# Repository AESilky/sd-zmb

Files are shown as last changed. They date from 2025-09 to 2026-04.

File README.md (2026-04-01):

# Silky Design & CMOS1 - Z80 Retro Motherboard

This is a Z80-based 'retro-style' Single Board Computer (motherboard).

The motherboard includes enough to run stand-alone.
That includes:

1. Z80 CPU
2. Selectable CPU clock frequencies
3. Reset circuit, divided into a POR board/system reset and a Z80/CPU only reset
4. Memory Management Unit (MMU) that provides bank selecting 8 of 64 8K banks (2M physical address)
5. 512K bytes RAM and 512K bytes Flash ROM
6. 2 Serial ports. One with USB 'device' interface, one with USB host interface (KBD)
7. RP2040 module to provide USB Host (for a keyboard) and an SD Card interface. The SD Card can be used for:
   a. EEPROM (like) configuration storage
   b. Virtual IDE drive(s)
   c. Raw SD Card access
   d. Multicolor LED indicator (via the onboard NeoPixel)
8. Programmable BAUD rate generator
9. Periodic interrupt generated by 3rd CTC channel
10. OLED or TFT graphics display (can be used for graphics or multi-line text)
11. RC2014-80 Extended/Enhanced Bus

The design started with much more on the board, but has been paired down to make the size and complexity of the board more reasonable. The 'features' that have been removed have been moved into projects of their own to be built-out as expansion boards.

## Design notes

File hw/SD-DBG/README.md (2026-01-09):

# ZMB Debug Board

The ZMB Debug Board is intended to provide debugging functionality to accompany the Mini-ZED Monitor firmware.

## Features

The board plugs into the RC80 bus and provides:

1. Jumper selectable memory wait-state generation, 0 to 8 wait states on memory operations.
2. Jumper selectable I/O wait-state generation, 0 to 8 wait states on I/O operations.
3. Reset push-button switch for Board/System reset. Holds the board/system in reset as long as the switch is pressed.
4. Reset push-button switch for CPU only reset. Holds the CPU in reset as long as the switch is pressed.
5. Breakpoint push-button switch. Generates the Z80 'special' reset signal when pressed.
6. Breakpoint hardware. Generates the Z80 'special' reset when selected conditions are met (see below for details)
7. LED indicators for the Z80 control signals (WAIT, HALT, RFSH, M1, MREQ, IORQ, RD, WR)
8. Optional Der Blinkenlights for A0-23 and D0-7. These are powered by a USB-C (power only) connector.

## Breakpoint Conditions

The breakpoint logic allows selecting:

1. Instruction fetch from a specific address (24 or 16 bit address)
2. Instruction fetch from any address (used for single-step)
3. Memory read from a specific address (24 or 16 bit address)
4. Memory write to a specific address (24 or 16 bit address)
5. Any memory operation on a specific address (24 or 16 bit address)
6. I/O read from a specific address (16 or 8 bit address)
7. I/O write to a specific address (16 or 8 bit address)
8. Any I/O operation on a specific address (16 or 8 bit address)

When the condition is met the Z80 'special' reset is generated, then the PC address of the following (ignored) instruction fetch address is recorded. Along with the PC address, the breakpoint condition that was met is also recorded. The recorded address and breakpoint condition can be read using I/O operations.

## High-Level Debug Monitor Description

This section provides a very high-level description of the Debug Monitor functionality. For complete information, see the Mini-ZDB Manual.

The monitor uses the terminal input/output subsystem of the ZMB to communicate with the user. It works stand-alone and in conjunction with the ZMB Debug Board (ZDB) to:

1. Display the CPU registers
2. Set the value of CPU registers that will be used when code is run
3. Display the contents of memory (ZDB not required)
4. Modify the contents of RAM memory (ZDB not required)
5. Display data from an I/O port (ZDB not required)
6. Write data to an I/O port (ZDB not required)
7. Run code and break:
   1. at one of 10 'soft' breakpoints (break location in RAM, ZDB not required)
   2. at any single location (location in RAM or ROM, ZDB required)
   3. when a memory write occurs to a specific address (ZDB required)
   4. when a memory read occurs from a specific address (ZDB required)
   5. when an I/O write occurs to a specific port (8 or 16 bit address, ZDB required)
   6. when an I/O read occurs from a specific port (8 or 16 bit address, ZDB required)
8. Single-step code (in RAM or ROM, ZDB required)
9. Perform operations that can be helpful in troubleshooting/repairing hardware problems, including:
   1. repetitive write of a specific data byte to a memory location
   2. repetitive read from a memory location *
   3. repetitive write of a specific data byte to a port
   4. repetitive read from a port
   5. run a memory test using a number of different approaches (data patterns)
10. Write a data file (ROM image, or portion) to the Flash. The source of the image can be:
    1. A file on the SD Card
    2. Received from the host computer using the serial port
11. Save an image of the Flash (or portion of it), as a data file. The destination can be:
    1. A file on the SD Card
    2. Sent to the host computer using the serial port

## RC80 Bus Debug Board (ZDB) Key Operation Details

This section provides details of how the ZDB performs key operations.

### Wait-State Generation

The ZDB can introduce a selectable number of wait-states in memory and/or I/O operations. This can allow using expansion boards that are not capable of running at the speed of the ZMB, but weren't designed to request wait-states.

The circuit that generates the WAIT- signal is similar for both memory and I/O. Two identical circuits are used, one for memory and one for I/O.

1. MREQ-/IORQ- holds a shift register (of the applicable circuit) in reset while the signal isn't active, resulting in all 8 of the shift register outputs being low.
2. When the MREQ-/IORQ- signal becomes active, the shift register clocks a 1 in on each rising edge of the CPU clock.
3. As 1 is clocked in, it appears on the shift register outputs from 1-8.
4. A jumper is placed on 1 of 9 positions:
   1. GND, which never generates a WAIT- signal
   2. One of the 8 shift register outputs, which results in 1 wait state through 8 wait states being generated

### Z80 Special Reset Generation

The circuit to generate the Z80 special reset is from the Zilog patent, U.S. Patent 4,486,827. It is triggered by either the press of a push-button switch or the breakpoint condition met circuit.

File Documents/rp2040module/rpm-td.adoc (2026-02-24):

= RP2040-Module: Technical Design
include::../adoc/settings.adoc[]
:organization: SilkyDESIGN
// Multi-Part Book: [Quick Start][User Guide]
:doctype: book
:description: Technical design for the RP2040 Module.
:imagesdir: ./images

toc::[]

[introduction]
= Introduction
The RP2040 Module is used to provide an interface from an 8-bit CPU bus to multiple peripherals, 
such as a USB keyboard, SD-Card, RTC and other I2C devices. 

The module uses GPIO pins for the CPU bus
interface, with 8 data bits, a module select *ms-*(((ms-, module select))), read *rd-*, write *wr-*, 
and address (control/data) *addr*, inputs, and wait *wait-* and interrupt request *int-* outputs.

It uses the built-in USB port to interface to a keyboard, SPI (through GPIO pins) for an SD-Card, and I2C 
(through GPIO pins) for an RTC module (and possibly other devices).

[preface%nonfacing]
= Preface
Needed?

[%nonfacing]
== Address 0/1 - Control and Data (Registers)
The module uses two addresses in the main system. One for module control and the other for peripheral
control and data. Each address can be written and read. The specifics of what is written and read
depends on the address and the selected peripheral.

=== Addr LOW - Module Control (Register 0)
The *addr* pin LOW selects the *Module Control* register. The Module Control register contains the
following bits:

[cols="1,1,1,1,1,1,1,1,1"]
|===
|7|6|5|4|3|2|1|0|
| | | | | | | |*| Function Control/Data
| | | | |*|*|*| | Function Select
| | | |*| | | | | Interrupt Enable
| | | | | | | | |
| |*| | | | | | | Busy (read)
|*| | | | | | | | Interrupt Pending (read)
|*| | | | | | | | Interrupt Being Serviced/Clear
|===

=== Addr HIGH - Function Dependent (Register 1)
The *addr* pin HIGH selects register 1 which is used by the module functions. The meaning/use of
register 1 depends on which function is selected. It also depends on the state of bit-0 of the
control register. When the control register bit-0 is 0, register 1 is typically used for function
control. When the control register bit-0 is 1, register 1 is typically used for data.

The following sections describe Register 0 and the use of Register 1 for the main module control
functionality in more detail.

=== Register 0 Bit Usage
Register 0 is used to control the high-level functionality of the module as follows:

Bit 0       Controls whether Register 1 is function control (0) or function data (1)
Bits 1-3    Function select
    000     Module
    001     Keyboard
    010     RTC
    011     -TDB-
    100     SD Card (func 0 - IDE)
    101     SD Card (func 1 - FILES)
    110     SD Card (func 2 - RAW)
    111     SD Card (func 3 - NVRAM)
Bit 4       Interrupt Enable (write) / Enabled (read)
Bit 5       -TBD-
Bit 6       -TBD-
Bit 7       Interrupt Pending (read)
            Interrupt Being Serviced (write '1')
            Interrupt Clear (write '0')

==== Bit 7 - Interrupt Pending (read) / Servicing:Clear (write 1:0)
When reading register 0, bit 7 '1' indicates that an interrupt is pending. When an interrupt is
pending, writing bit 7 as '1' at the same time as selecting a function with bits 1-3 (along with bit 0)
pauses the currently selected function, stores it, and selects the indicated function. This allows
servicing an interrupt from a function that is different than the function currently in use. Each
time register 0 is written, but 7 should be written as 1 while interrupts are being serviced. Once
bit 7 has been written with '1', writing it with '0' resets the interrupt pending flag and will
allow the module to generate another interrupt if interrupts are enabled (bit 4 is 1). In addition to
resetting the interrupt pending, the write of '0' also restores the previously selected function as
the active function regardless of what is written to bits 0-3. This allows the continued processing
of the interrupted function without any additional changes to the module.

[%nonfacing]
== Bus Service
The module uses 8 GPIO pins for a bidirectional data bus, 4 GPIO for module select, write, read, and address
inputs, and 2 GPIO pins as wait request and interrupt request outputs. The GPIOs are monitored and
controlled by the RP2040 Programmable I/O (PIO).

=== PIO State Machine Use
Two state machines are used to wait for Module Select together with Read or Write. One State
Machine waits on an internal interrupt bit to be set, signalling that the data bus needs to be
read and the data transferred in.

One State Machine waits on Module Select (MS-). Once MS- is detected, RD- is checked along with MS-.
If both are detected together the WAIT- pin is activated and an interrupt is generated to the module CPU

A second State Machine waits on Module Select (MS-). Once MS- is detected, WR- is checked along with MS-.
If both are detected together the WAIT- pin is activated and an interrupt bit is set to trigger
another State Machine to read the bus.

A third State Machine waits on an interrupt bit to be set. Once the interrupt is set, allowing the
State Machine to continue, the 8 data pins are read and the data pushed to the ISR. The State
Machine then goes back to waiting on the interrupt bit.

A forth State Machine waits on data arriving in the OSR and when data is available it sets the
8 data pins to output, writes the byte, clears the WAIT- pin, and sets in interrupt bit.

[%nonfacing]
==== ((sec-level-4))
This is a 4th level section

ifeval::["{backend}" == "pdf"]
[index]
= Index
endif::[]

[colophon]
= Colophon
This is the design document for ((RP2040-Module)) ((Version 0.1.0))
Edit date: 1-17-2026

MIT License

Copyright (c) 2020-24 PyKOB - MorseKOB in Python

This document is authored using *asciidoc*, and the pdf version rendered through
*asciidoctor-pdf*, to create a manual that is more readable and more pleasing to the eye.

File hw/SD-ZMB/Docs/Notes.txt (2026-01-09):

We should replace the act244 with a 245 and add a 245 to the lower address bus, with that the full address bus is buffered as well as  ZMREQ. ZIORQ, RD and WR.  Add a 125 or 367 for the bus status read.  That allows us to move some if not most of the signals to the Z80 no buffer delays. We need to get MREQ out of the paging RAM, to give us more access time. Please add pull ups to ZMREQ, ZIORQ, ZRD and ZWR so they are a known state when tri-stated and not floating.

That is what I am thinking to minimize the delays between the Z80 and memory, plus the onboard devices (no we treat our board per as local friends). We still need to consider the expansion board area and instruction fetches maybe those off board accesses will require a wait state to be inserted. The Z80 is a very slow device in respect to the clock, including its needs for data setup. Only 2 clock times for all that work to be done. So the paging register is always in series, we must have it on the first available stable signal (addresses), and take advantage some of the control signals might be ok with the MREQ delayed by a ½ of a clock. All of this close timing is connected to M1 (instruction fetch). We do have M1 which is also based off the start of the 2 bit clock cycle, so we know it’s a read, nothing else. Don’t forget that with only 2 cycles to make all this happen. 

I am going with the assumption that we are targeting to run at 6 MHz or 12 MHz using a Z84C0006 or a Z84C0020. The SRAM and FLASH would have a 55ns access time.

Our first priority is to get the addresses stable and to the devices in the quickest way. Next is to keep the memory devices RD/WR controls fast. At 6MHz CLK to address is 90ns. CLK to MREQ is a 154ns. Including the required setup for data in is 333ns -30ns of setup, just say 300ns.

At 12MHz assuming a z80c0020, CLK to address is 57ns, and CLK to MREQ 87ns with a two cycle time of 167ns, minus the 12ns of setup time for the z80. I think that gives us 98ns off the address and only 80ns from MREQ not accounting for any additional delays in the logic.

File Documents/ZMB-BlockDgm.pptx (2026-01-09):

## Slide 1

ZMB Block Diagram (ES)

RESET
- Board (driven by):
  - Power-On
  - Push-BTN
  - Bus Signal
- Z80 (driven by):
  - Board-RST
  - Bus Signal

I/O
Decode

BRD-Ctrl WR

DATA

BRDRST

PgEN WR

D0

Z80RST

Paging
Enable

Z80RST
disables
paging

Pg Enable

MMU & Memory
(64KB Logical : 2MB Physical)

When Paging is disabled PA13-PA23 are 0 (ROM is selected)

COM1
(D,RTC,CTS)

COM2
(TX,RX)

BRD Status (via DCDA,CTSB)

Paging-Enabled, NMI-Enabled

Misc Ctrl (via HSHK)

SIO

A[0..1]

SIO-SEL

INT

DATA

Ext INT REQ (via DCDB)

CTC-SEL

A[0..1]

DATA

CTC

- CH1: BAUD1
- CH2: BAUD2
- CH3: Periodic INT

BAUD1

BAUD2

USB

INT

Z80RST

Page-Seg
Register

Page[PA:13-15]

Paging Ctrl

Flash
ROM
[00:0000-07:FFFF]
(512MB)

RAM
[08:0000-0F:FFFF]
(512MB)

Available
(to expansion boards)
[10:0000-1F:FFFF]
(1MB)

PS-Reg WR

ADDR:12-15

DATA

PS-Reg WR

Pg Enable

Physical Address
[00:0000-1F:FFFF]

PS-Reg RD

PgEn WR

BRD-Ctrl WR

DisplayPanel-SEL

CTC-SEL

SIO-SEL

SDMod-SEL

Board
Control

- NMI Enable
- LED[0..4]

LED[0..4]

NMI Enable

PS-Reg RD

DATA

PS-RD

Display Panel

DisplayPanel-SEL

A[0..1]

DATA

USB KBD
SD Card
(module)

SDMod-SEL

A[0..1]

DATA

COM2

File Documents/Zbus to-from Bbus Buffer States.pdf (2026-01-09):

In the following…
ZD: Z80 Data | ZA: Z80 Address | ZC: Z80 Control (MREQ, IORQ, WR, RD)
BD: Bus (expansion) Data | BA: Bus Address | BC: Bus Control
MB: Main Board Device
EB: Expansion Board Device (on the Bus)
Required: This must occur
Allowed: This can occur (it will not bother anything)
Prohibited: This is not allowed
Master | Operation | ZD<=>BD | ZA<=>BA | ZC<=>BC
| | Required | Allowed | Prohibited | Valid nS (long path) | Required | Allowed | Prohibited | Valid nS (long path) | Required | Allowed | Prohibited | Valid nS (long path)

Z80 Master
| MB Memory RD (IF, MR below 1M) | | ZD => BD | BD <= ZD | | | ZA0-12+MHA13-23=>BA | BA<=ZA | | | ZC=>BC | BC<=ZC
BUS Memory RD (IF, MR above 1M) | BD => ZD | MB device on ZD | 52 (BUSMEM-) | ZA0-12+MHA13-23=>BA | ZC=>BC
MB Memory WR (MW below 1M) | ZD => BD | BD => ZD | ZA0-12+MHA13-23=>BA | BA<=ZA | ZC=>BC | BC<=ZC
BUS Memory WR (MW above 1M) | ZD => BD | MB device on ZD | 52 (BUSMEM-) | ZA0-12+MHA13-23=>BA | ZC=>BC
MB Refresh | | | ZA=>BA | BA<=ZA | ZC=>BC | BC<=ZC
MB I/O RD | ZD => BD | BD <= ZD | ZA0-15=>BA | BA<=ZA | ZC=>BC | BC<=ZC
BUS I/O RD | BD => ZD | MB device on ZD | 52 (BUSIO-) | ZA0-15=>BA | ZC=>BC
MB I/O WR | ZD => BD | BD => ZD | ZA0-15=>BA | BA<=ZA | ZC=>BC | BC<=ZC
BUS i/O WR | ZD => BD | 52 (BUSIO-) | ZA0-15=>BA | ZC=>BC
MB INT-ACK | ZD => BD | | ZA0-15=>BA | BA<=ZA | ZC=>BC | BC<=ZC
BUS INT-ACK | BD => ZD | 30 (IORQ-) | ZA0-15=>BA | BA<=ZA | ZC=>BC | BC<=ZC
Master | Operation | ZD<=>BD | | ZA<=>BA | ZC<=>BC
BUS Master
| | Required | Allowed | Prohibited | Required | Allowed | Prohibited | Required | Allowed | Prohibited
MB Memory RD (IF, MR below 1M) | ZD => BD | 44 (RD-) | BA=>ZA0-12+MHA13-23 | 42 (LCLMEM-) | BC=>ZC | 42 (LCLMEM-)
BUS Memory RD (IF, MR above 1M) | BD => ZD | ZD => BD | BA=>ZA0-12+MHA13-23 | ZA=>BA | BC=>ZC | ZC=>BC
MB Memory WR (MW below 1M) | BD => ZD | MB Device on ZD | 44 (WR-) | BA=>ZA0-12+MHA13-23 | 42 (LCLMEM-) | BC=>ZC | 42 (LCLMEM-)
BUS Memory WR (MW above 1M) | BD => ZD | ZD => BD | BA=>ZA0-12+MHA13-23 | ZA=>BA | BC=>ZC | ZC=>BC
MB I/O RD | ZD => BD | 44 (RD-) | BA=>ZA0-15 | 40 (LCLIO-) | BC=>ZC
BUS I/O RD | BD => ZD | ZD => BD | BA=>ZA0-15 | ZA=>BA | BC=>ZC | ZC=>BC | 42 (LCLMEM-)
MB I/O WR | BD => ZD | MB Device on ZD | 44 (WR-) | BA=>ZA0-15 | 40 (LCLIO-) | BC=>ZC | 40 (LCLIO-)
BUS i/O WR | BD => ZD | ZD => BD | BA=>ZA0-15 | ZA=>BA | BC=>ZC | ZC=>BC
MB INT-ACK | ZD => BD | 30 (IORQ-) | BA=>ZA0-15 | ZA=>BA | BC=>ZC | 40 (LCLIO-)
BUS INT-ACK | BD => ZD | BA=>ZA0-15 | ZA=>BA | BC=>ZC | ZC=>BC

ZD <=> BD, ZA<=>BA, ZC<=>BC Buffer States

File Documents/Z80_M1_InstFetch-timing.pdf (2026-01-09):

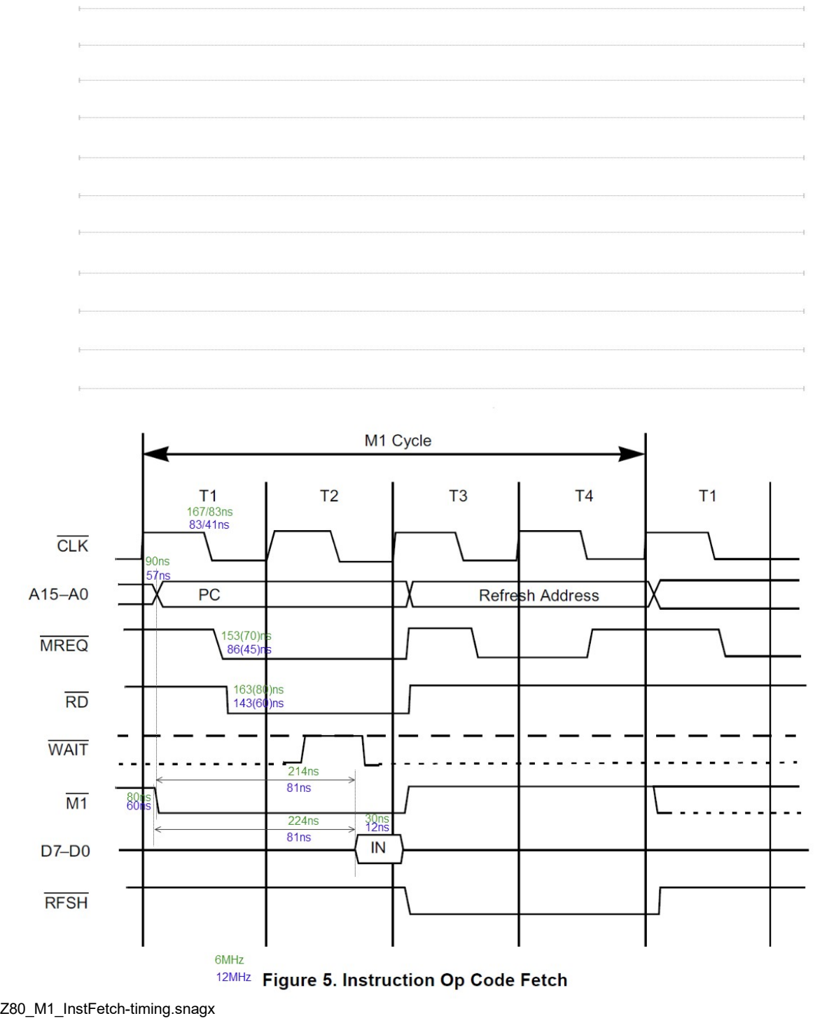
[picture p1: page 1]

Z80_M1_InstFetch-timing.snagx

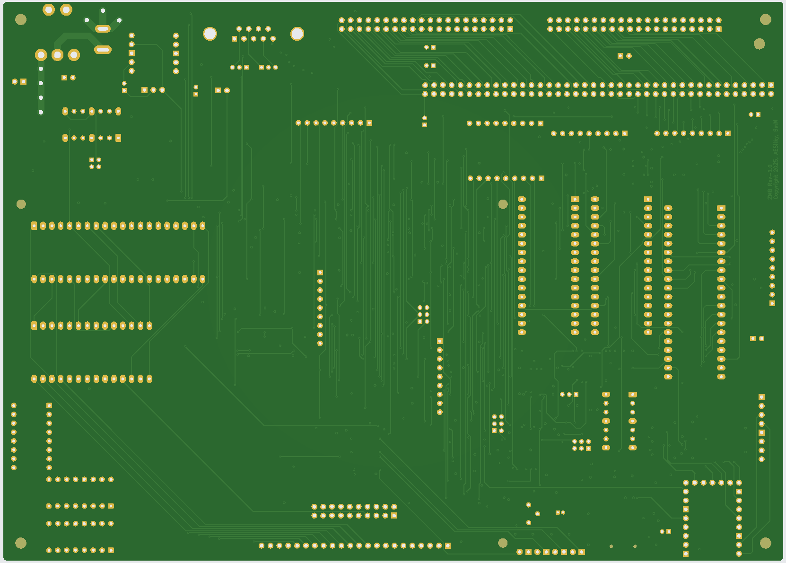
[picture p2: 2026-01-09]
Documents/images/ZMB-PCB-bare_back.png

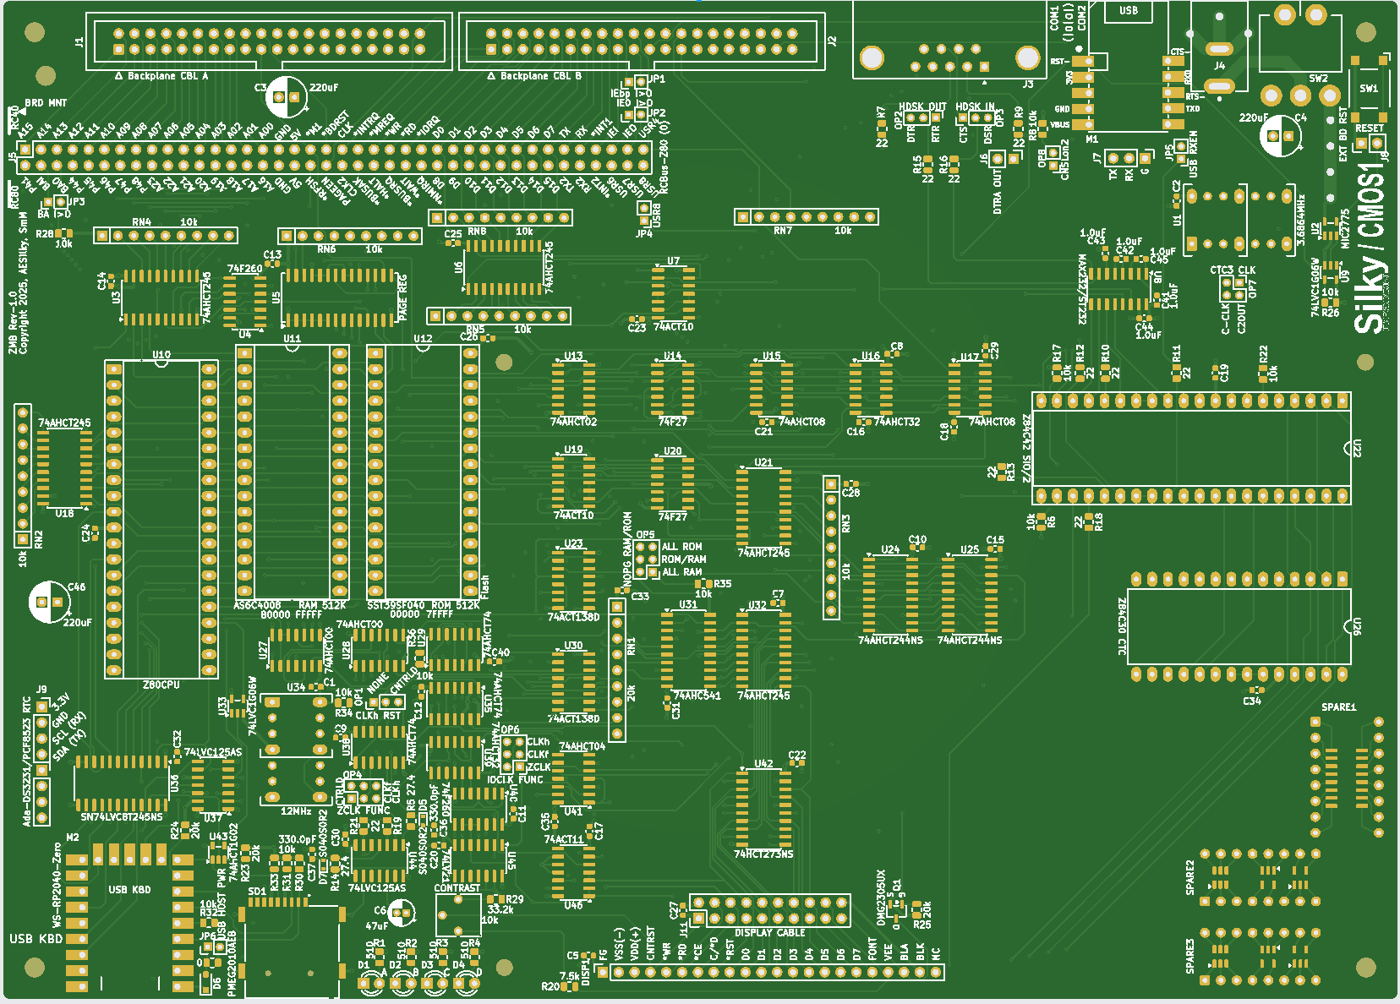
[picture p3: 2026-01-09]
Documents/images/ZMB-PCB-bare.png

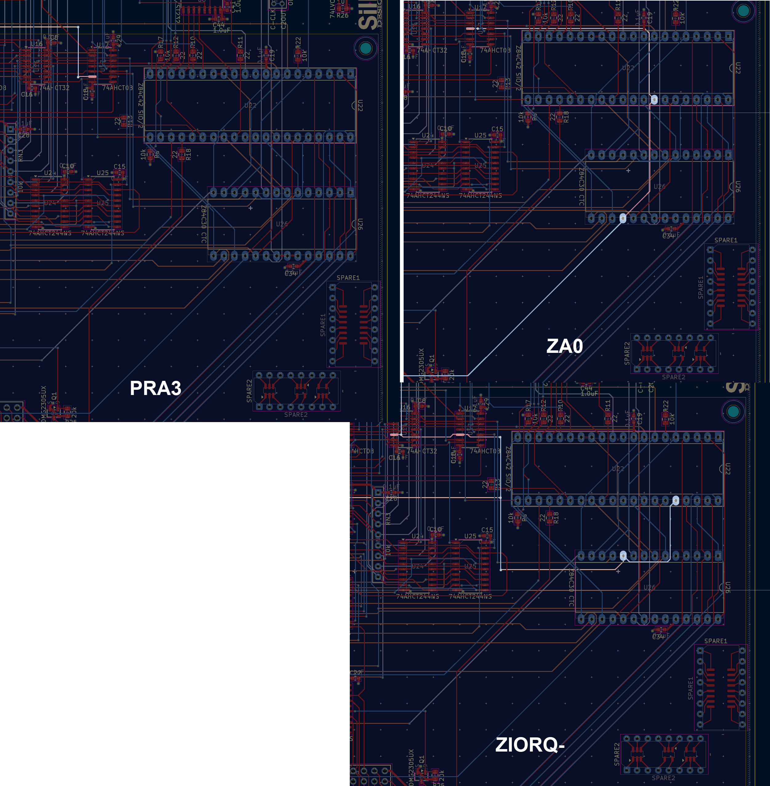
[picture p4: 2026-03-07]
hw/SD-ZMB/ECO/ECO-A-Traces.png

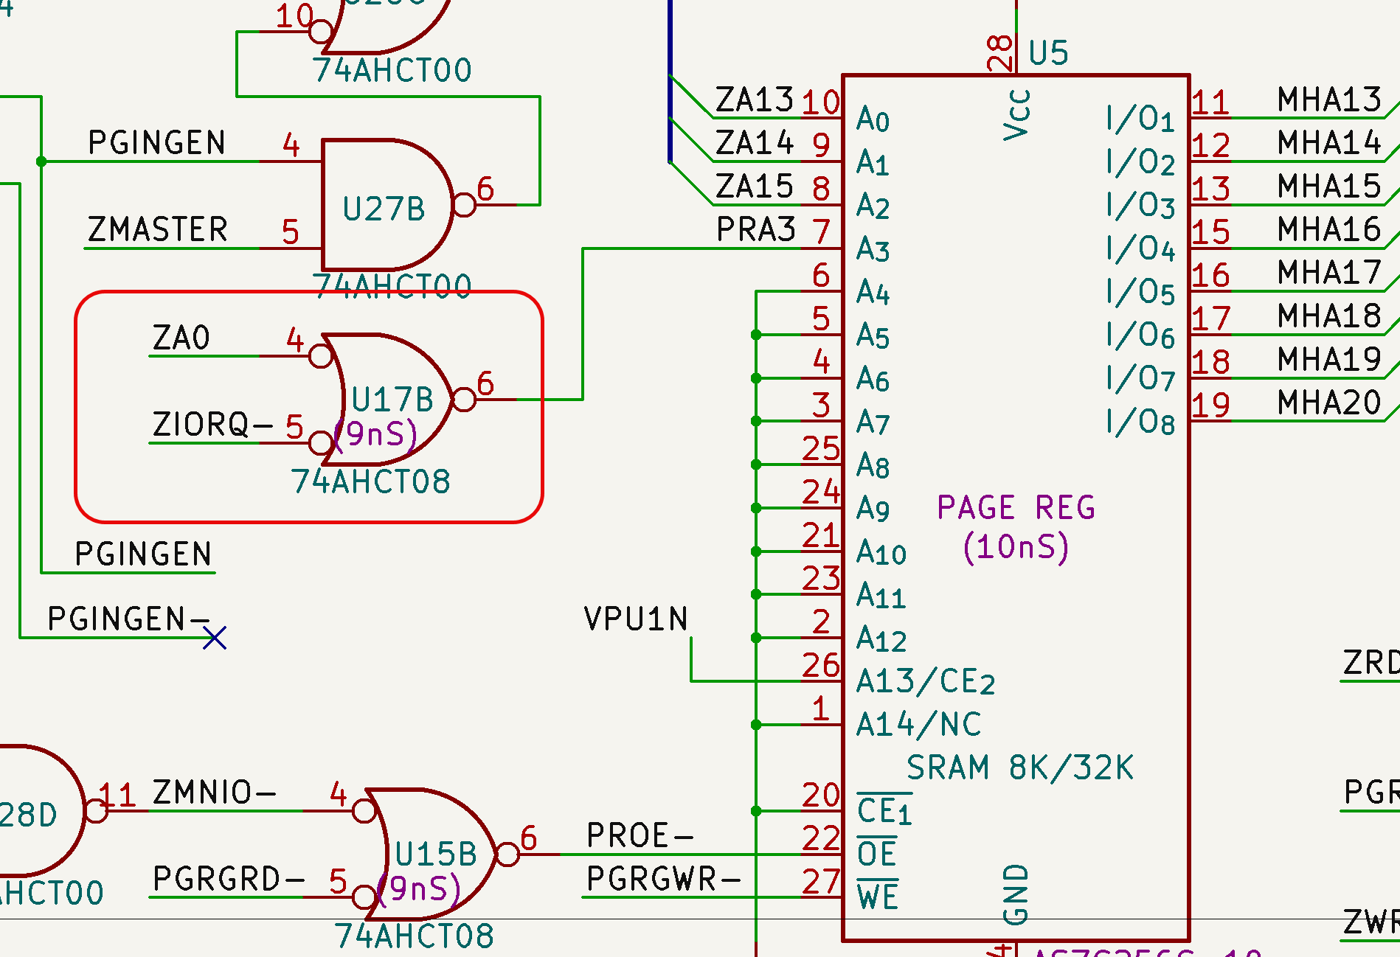
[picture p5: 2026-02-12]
hw/SD-ZMB/ECO/ECO-A-Was.png

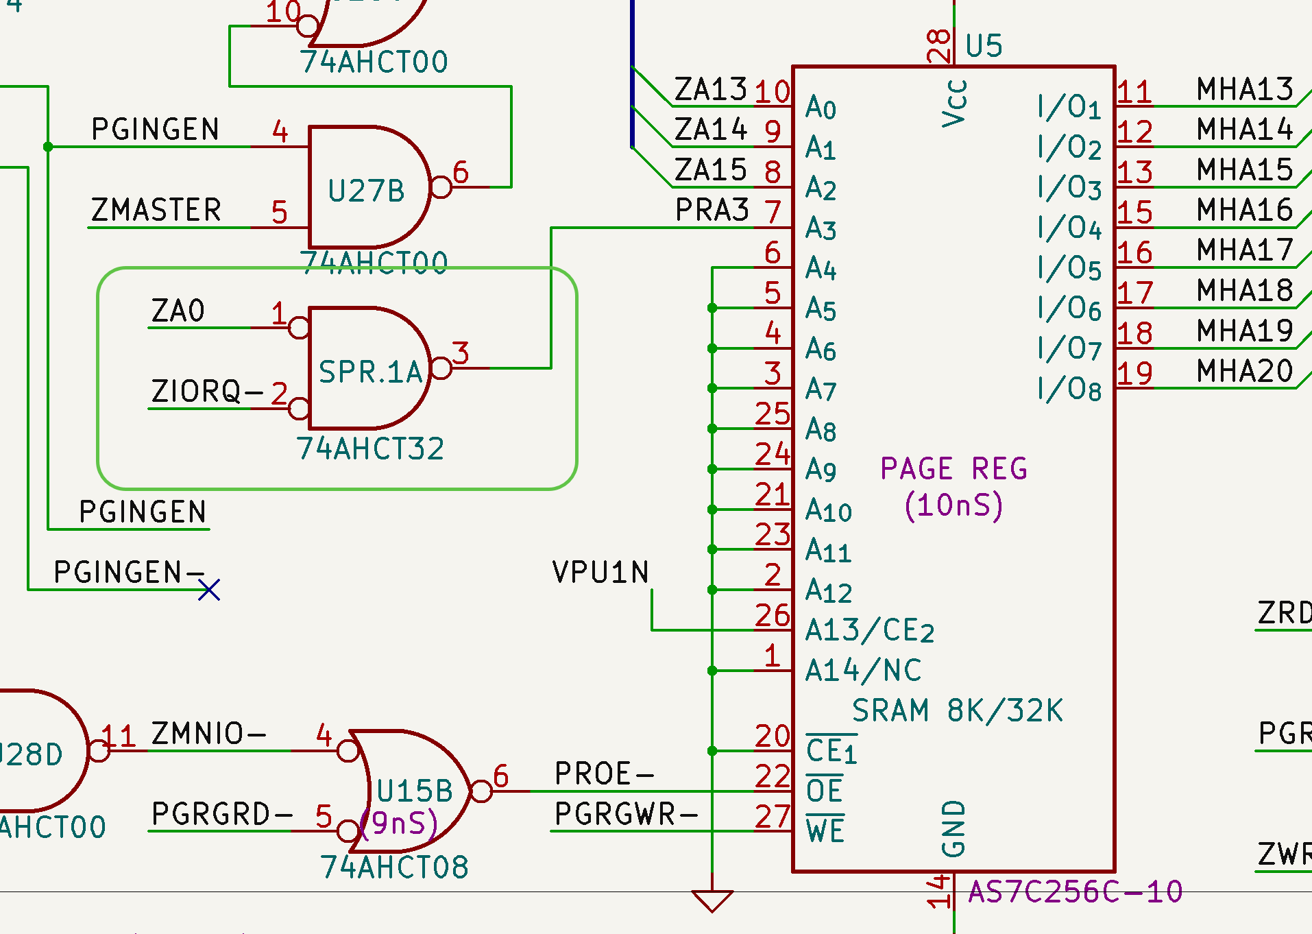
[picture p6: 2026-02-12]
hw/SD-ZMB/ECO/ECO-A-SB.png

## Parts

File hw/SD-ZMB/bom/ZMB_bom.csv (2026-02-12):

null | Sourced | Placed | References | Value | Footprint
1 |  |  | C1 | 0.1uF | C_0603_1608Metric
2 |  |  | C2 | 0.1uF | C_0603_1608Metric
3 |  |  | C5 | 0.1uF | C_0603_1608Metric
4 |  |  | C7 | 0.1uF | C_0603_1608Metric
5 |  |  | C8 | 0.1uF | C_0603_1608Metric
6 |  |  | C9 | 0.1uF | C_0603_1608Metric
7 |  |  | C10 | 0.1uF | C_0603_1608Metric
8 |  |  | C11 | 0.1uF | C_0603_1608Metric
9 |  |  | C12 | 0.1uF | C_0603_1608Metric
10 |  |  | C13 | 0.1uF | C_0603_1608Metric
11 |  |  | C14 | 0.1uF | C_0603_1608Metric
12 |  |  | C15 | 0.1uF | C_0603_1608Metric
13 |  |  | C16 | 0.1uF | C_0603_1608Metric
14 |  |  | C17 | 0.1uF | C_0603_1608Metric
15 |  |  | C18 | 0.1uF | C_0603_1608Metric
16 |  |  | C19 | 0.1uF | C_0603_1608Metric
17 |  |  | C20 | 0.1uF | C_0603_1608Metric
18 |  |  | C21 | 0.1uF | C_0603_1608Metric
19 |  |  | C22 | 0.1uF | C_0603_1608Metric
20 |  |  | C23 | 0.1uF | C_0603_1608Metric
21 |  |  | C24 | 0.1uF | C_0603_1608Metric
22 |  |  | C25 | 0.1uF | C_0603_1608Metric
23 |  |  | C26 | 0.1uF | C_0603_1608Metric
24 |  |  | C27 | 0.1uF | C_0603_1608Metric
25 |  |  | C28 | 0.1uF | C_0603_1608Metric
26 |  |  | C29 | 0.1uF | C_0603_1608Metric
27 |  |  | C30 | 0.1uF | C_0603_1608Metric
28 |  |  | C31 | 0.1uF | C_0603_1608Metric
29 |  |  | C32 | 0.1uF | C_0603_1608Metric
30 |  |  | C33 | 0.1uF | C_0603_1608Metric
31 |  |  | C34 | 0.1uF | C_0603_1608Metric
32 |  |  | C35 | 0.1uF | C_0603_1608Metric
33 |  |  | C40 | 0.1uF | C_0603_1608Metric
34 |  |  | C41 | 1.0uF | C_0603_1608Metric
35 |  |  | C42 | 1.0uF | C_0603_1608Metric
36 |  |  | C43 | 1.0uF | C_0603_1608Metric
37 |  |  | C44 | 1.0uF | C_0603_1608Metric
38 |  |  | C45 | 1.0uF | C_0603_1608Metric
39 |  |  | C3 | 220uF | CP_Radial_D6.3mm_P2.50mm
40 |  |  | C4 | 220uF | CP_Radial_D6.3mm_P2.50mm
41 |  |  | C46 | 220uF | CP_Radial_D6.3mm_P2.50mm
42 |  |  | C36 | 330.0pF | C_0603_1608Metric
43 |  |  | C37 | 330.0pF | C_0603_1608Metric
44 |  |  | C6 | 47uF | CP_Radial_D4.0mm_P1.50mm
45 |  |  | R6 | 10k | R_0805_2012Metric
46 |  |  | R8 | 10k | R_0805_2012Metric
47 |  |  | R17 | 10k | R_0805_2012Metric
48 |  |  | R22 | 10k | R_0805_2012Metric
49 |  |  | R26 | 10k | R_0805_2012Metric
50 |  |  | R28 | 10k | R_0805_2012Metric
51 |  |  | R30 | 10k | R_0805_2012Metric
52 |  |  | R31 | 10k | R_0805_2012Metric
53 |  |  | R32 | 10k | R_0805_2012Metric
54 |  |  | R33 | 10k | R_0805_2012Metric
55 |  |  | R34 | 10k | R_0805_2012Metric
56 |  |  | R35 | 10k | R_0805_2012Metric
57 |  |  | R36 | 10k | R_0805_2012Metric
58 |  |  | R7 | 22 | R_0805_2012Metric
59 |  |  | R9 | 22 | R_0805_2012Metric
60 |  |  | R10 | 22 | R_0805_2012Metric
61 |  |  | R11 | 22 | R_0805_2012Metric
62 |  |  | R12 | 22 | R_0805_2012Metric
63 |  |  | R13 | 22 | R_0805_2012Metric
64 |  |  | R15 | 22 | R_0805_2012Metric
65 |  |  | R16 | 22 | R_0805_2012Metric
66 |  |  | R18 | 22 | R_0805_2012Metric
67 |  |  | R19 | 22 | R_0805_2012Metric
68 |  |  | R21 | 22 | R_0805_2012Metric
69 |  |  | R1 | 510 | R_0805_2012Metric
70 |  |  | R2 | 510 | R_0805_2012Metric
71 |  |  | R3 | 510 | R_0805_2012Metric
72 |  |  | R4 | 510 | R_0805_2012Metric
73 |  |  | R23 | 20k | R_0805_2012Metric
74 |  |  | R24 | 20k | R_0805_2012Metric
75 |  |  | R25 | 20k | R_0805_2012Metric
76 |  |  | R5 | 27.4 | R_0805_2012Metric
77 |  |  | R14 | 27.4 | R_0805_2012Metric
78 |  |  | R20 | 7.5k | R_0805_2012Metric
79 |  |  | R27 | 0 | R_0805_2012Metric
80 |  |  | R29 | 33.2k | R_0805_2012Metric
81 |  |  | D1 | LED RED | LED_D3.0mm
82 |  |  | D2 | LED RED | LED_D3.0mm
83 |  |  | D3 | LED RED | LED_D3.0mm
84 |  |  | D5 | BAS7002VH6327XTSA1 | D_SOD-523
85 |  |  | D7 | BAS7002VH6327XTSA1 | D_SOD-523
86 |  |  | D4 | LED GREEN | LED_D3.0mm
87 |  |  | D6 | PMEG2010AEB | D_SOD-323_HandSoldering
88 |  |  | U3 | 74AHCT245 | SO-20_5.3x12.6mm_P1.27mm
89 |  |  | U6 | 74AHCT245 | SO-20_5.3x12.6mm_P1.27mm
90 |  |  | U18 | 74AHCT245 | SO-20_5.3x12.6mm_P1.27mm
91 |  |  | U21 | 74AHCT245 | SO-20_5.3x12.6mm_P1.27mm
92 |  |  | U32 | 74AHCT245 | SO-20_5.3x12.6mm_P1.27mm
93 |  |  | U29 | 74AHCT74 | SOIC-14_3.9x8.7mm_P1.27mm
94 |  |  | U35 | 74AHCT74 | SOIC-14_3.9x8.7mm_P1.27mm
95 |  |  | U38 | 74AHCT74 | SOIC-14_3.9x8.7mm_P1.27mm
96 |  |  | U4 | 74F260 | SOIC-14_3.9x8.7mm_P1.27mm
97 |  |  | U40 | 74F260 | SOIC-14_3.9x8.7mm_P1.27mm
98 |  |  | U7 | 74ACT10 | SOIC-14_3.9x8.7mm_P1.27mm
99 |  |  | U19 | 74ACT10 | SOIC-14_3.9x8.7mm_P1.27mm
100 |  |  | U9 | 74LVC1G06W | SOT-23-5
101 |  |  | U33 | 74LVC1G06W | SOT-23-5
102 |  |  | U14 | 74F27 | SOIC-14_3.9x8.7mm_P1.27mm
103 |  |  | U20 | 74F27 | SOIC-14_3.9x8.7mm_P1.27mm
104 |  |  | U15 | 74AHCT08 | SOIC-14_3.9x8.7mm_P1.27mm
105 |  |  | U17 | 74AHCT08 | SOIC-14_3.9x8.7mm_P1.27mm
106 |  |  | U16 | 74AHCT32 | SOIC-14_3.9x8.7mm_P1.27mm
107 |  |  | U39 | 74AHCT32 | SOIC-14_3.9x8.7mm_P1.27mm
108 |  |  | U23 | 74ACT138D | SOIC-16_3.9x9.9mm_P1.27mm
109 |  |  | U30 | 74ACT138D | SOIC-16_3.9x9.9mm_P1.27mm
110 |  |  | U24 | 74AHCT244NS | SO-20_5.3x12.6mm_P1.27mm
111 |  |  | U25 | 74AHCT244NS | SO-20_5.3x12.6mm_P1.27mm
112 |  |  | U27 | 74AHCT00 | SOIC-14_3.9x8.7mm_P1.27mm
113 |  |  | U28 | 74AHCT00 | SOIC-14_3.9x8.7mm_P1.27mm
114 |  |  | U37 | 74LVC125AS | SOIC-14_3.9x8.7mm_P1.27mm
115 |  |  | U44 | 74LVC125AS | SOIC-14_3.9x8.7mm_P1.27mm
116 |  |  | U1 | 3.6864MHz Can Osc | OSC-8_14-AES
117 |  |  | U2 | MIC2775 | SOT-23-5
118 |  |  | U5 | SRAM 8K/32K | SOJ-28_7.62x18.415mm_P1.27mm
119 |  |  | U8 | MAX232/ST232 | SOIC-16_3.9x9.9mm_P1.27mm
120 |  |  | U10 | Z80CPU | DIP-40_W15.24mm_Socket_LongPads
121 |  |  | U11 | AS6C4008 | DIP-32_W15.24mm_Socket_LongPads
122 |  |  | U12 | SST39SF040 | DIP-32_W15.24mm_Socket_LongPads
123 |  |  | U13 | 74AHCT02 | SOIC-14_3.9x8.7mm_P1.27mm
124 |  |  | U22 | Z84C42 SIO/2 | DIP-40_W15.24mm_Socket_LongPads
125 |  |  | U26 | Z84C30 CTC | DIP-28_W15.24mm_LongPads
126 |  |  | U31 | 74AHC541 | SO-20_5.3x12.6mm_P1.27mm
127 |  |  | U34 | 12MHz Can Osc | OSC-8_14-AES
128 |  |  | U36 | SN74LVC8T245NS | SO-24_5.3x15mm_P1.27mm
129 |  |  | U41 | 74AHCT04 | SOIC-14_3.9x8.7mm_P1.27mm
130 |  |  | U42 | 74HCT273NS | SO-20_5.3x12.6mm_P1.27mm
131 |  |  | U43 | 74AHCT1G02 | SOT-23-5
132 |  |  | U45 | 74LV21 | SOIC-14_3.9x8.7mm_P1.27mm
133 |  |  | U46 | 74ACT11 | SOIC-14_3.9x8.7mm_P1.27mm
134 |  |  | SW1 | SW_Push | AES-SW_PUSH_SMD_1P1T_NO_6x6mm
135 |  |  | SW2 | SW Toggle PCB | SW-SPDT-PCB-TGL-RA-AES
136 |  |  | RN2 | 10k | R_Array_SIP9
137 |  |  | RN3 | 10k | R_Array_SIP9
138 |  |  | RN4 | 10k | R_Array_SIP9
139 |  |  | RN5 | 10k | R_Array_SIP9
140 |  |  | RN6 | 10k | R_Array_SIP9
141 |  |  | RN7 | 10k | R_Array_SIP9
142 |  |  | RN8 | 10k | R_Array_SIP9
143 |  |  | JP1 | CONN 1x02 HDR Pins 2mm | PinHeader_1x02_P2.00mm_Vertical
144 |  |  | JP2 | CONN 1x02 HDR Pins 2mm | PinHeader_1x02_P2.00mm_Vertical
145 |  |  | JP3 | CONN 1x02 HDR Pins 2mm | PinHeader_1x02_P2.00mm_Vertical
146 |  |  | JP4 | CONN 1x02 HDR Pins 2mm | PinHeader_1x02_P2.00mm_Vertical
147 |  |  | JP5 | HDR 1x02 Pin | PinHeader_1x02_P2.00mm_Vertical
148 |  |  | OP8 | HDR 1x02 Pin | PinHeader_1x02_P2.00mm_Vertical
149 |  |  | OP2 | AES-Option_A-B | PinHeader_1x03_P2.00mm_Vertical
150 |  |  | OP3 | AES-Option_A-B | PinHeader_1x03_P2.00mm_Vertical
151 |  |  | OP4 | CONN 2x3 HDR | PinHeader_2x03_AB_2mm-AES
152 |  |  | OP6 | CONN 2x3 HDR | PinHeader_2x03_AB_2mm-AES
153 |  |  | SPARE2 | ~ | SPARE-16-SOT-5_6-AES
154 |  |  | SPARE3 | ~ | SPARE-16-SOT-5_6-AES
155 |  |  | DISP1 | DISPLAY | OLED-Disp-Socket-P2-8BitPI-AES
156 |  |  | M1 | AES-FTDI_FT234XF_USB_UART_Module | AES-FTDI-UMFT234XF
157 |  |  | M2 | WS-RP2040-Zero | RP2040_WS-ZERO-AES
158 |  |  | OP1 | AES-Opt_1_of_2 | PinHeader_1x03_P2.00mm_Vertical
159 |  |  | OP5 | HDR 02x03 | PinHeader_2x03_AB_2mm-AES
160 |  |  | OP7 | HDR 2x02 2mm | PinHeader_2x02_AB_2mm-AES
161 |  |  | Q1 | DMG2305UX | DMG2305-SOT-23-3-AES
162 |  |  | RN1 | 20k | R_Array_SIP9
163 |  |  | RV1 | 10k | Pot-Molence-Amazon-PCB-AES
164 |  |  | SD1 | MicroSD-Socket | AES-SDCard-GCT_MEM2075-00-140-01-A
165 |  |  | SPARE1 | ~ | SPARE-and-SOIC-16-AES
166 |  |  | J1 | HDR 02x20 PIN (Ribbon Socket) | IDC-Header_2x20_P2.54mm_Vertical
167 |  |  | J2 | HDR 02x20 PIN (Ribbon Socket) | IDC-Header_2x20_P2.54mm_Vertical
168 |  |  | J6 | HDR 1x02 Pin | PinHeader_1x02_P2.54mm_Vertical
169 |  |  | J8 | HDR 1x02 Pin | PinHeader_1x02_P2.54mm_Vertical
170 |  |  | J9 | HDR 1x04 Socket | PinSocket_1x04_P2.54mm_Vertical
171 |  |  | J10 | HDR 1x04 Socket | PinSocket_1x04_P2.54mm_Vertical
172 |  |  | J3 | DE9 Male (PINS) | DSUB9-Pins-AdamTech_DE09-PL-25-AES
173 |  |  | J4 | BARREL JACK | AES-CUI_PJ-037B
174 |  |  | J5 | SOCKET 02x40 (BRD-CONN) | RC80-BUS-BPMB-AES
175 |  |  | J7 | HDR 1x3 Pin | PinHeader_1x03_P2.54mm_Vertical
176 |  |  | J11 | HDR 2x10 Pin | PinHeader_2x10_P2.54mm_Vertical

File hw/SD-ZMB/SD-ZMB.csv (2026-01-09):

Reference | Qty | Value | DNP | Exclude from BOM | Exclude from Board | Footprint | Function
C1,C2,C5,C7,C8,C9,C10,C11,C12,C13,C14,C15,C16,C17,C18,C19,C20,C21,C22,C23,C24,C25,C26,C27,C28,C29,C30,C31,C32,C33,C34,C35,C40 | 33 | 0.1uF |  |  |  | Capacitor_SMD:C_0603_1608Metric
C3,C4,C44 | 3 | 220uF |  |  |  | Capacitor_THT:CP_Radial_D6.3mm_P2.50mm
C6 | 1 | 47uF |  |  |  | Capacitor_THT:CP_Radial_D4.0mm_P1.50mm
C36,C37 | 2 | 330.0pF |  |  |  | Capacitor_SMD:C_0603_1608Metric
C38,C39,C41,C42,C43 | 5 | 1.0uF |  |  |  | Capacitor_SMD:C_0603_1608Metric
D1,D2,D3 | 3 | LED RED |  |  |  | LED_THT:LED_D3.0mm | RED1,RED2,RED3
D4 | 1 | LED GREEN |  |  |  | LED_THT:LED_D3.0mm | GRN
D5,D7 | 2 | BAS7002VH6327XTSA1 |  |  |  | Diode_SMD:D_SOD-523
D6 | 1 | CDBF0130R |  |  |  | Diode_SMD:D_SOD-323_HandSoldering
H1,H2,H3,H4,H8 | 5 | MountingHole |  | Excluded from BOM |  | MountingHole:MountingHole_3.2mm_M3 | BRD MNT
H5,H6,H7 | 3 | MountingHole |  | Excluded from BOM |  | MountingHole:MountingHole_2.7mm_M2.5
J1,J3 | 2 | HDR 1x02 Pin |  |  |  | Connector_PinHeader_2.54mm:PinHeader_1x02_P2.54mm_Vertical | DTRA OUT,EXT BD RST
J4 | 1 | BARREL JACK |  |  |  | AES_Library:AES-CUI_PJ-037B
J8,J9 | 2 | HDR 02x20 PIN (Ribbon Socket) |  |  |  | Connector_IDC:IDC-Header_2x20_P2.54mm_Vertical | Backplane CBL A,Backplane CBL B
J10,J14 | 2 | HDR 1x04 Socket |  |  |  | Connector_PinSocket_2.54mm:PinSocket_1x04_P2.54mm_Vertical | I2C-RTC,RTC-SUPPORT
J12 | 1 | SOCKET 02x40 (BRD-CONN) |  |  |  | AES_Library:RC80-BUS-BPMB-AES | RCBus-Z80 (0)
J16 | 1 | HDR 1x3 Pin |  |  |  | Connector_PinHeader_2.54mm:PinHeader_1x03_P2.54mm_Vertical | COM2
J17 | 1 | HDR 2x10 Pin |  |  |  | Connector_PinHeader_2.54mm:PinHeader_2x10_P2.54mm_Vertical | DISPLAY CABLE
J18 | 1 | DE9 Male (PINS) |  |  |  | Connector_Dsub:DSUB-9_Pins_Horizontal_P2.77x2.84mm_EdgePinOffset9.90mm_Housed_MountingHolesOffset11.32mm | COM1
JP1,JP2,JP3,JP4 | 4 | CONN 1x02 HDR Pins 2mm |  |  |  | Connector_PinHeader_2.00mm:PinHeader_1x02_P2.00mm_Vertical | BA I>O,IE0 I>O,IEbp I>O,USR8
JP5 | 1 | HDR 1x02 Pin |  | Excluded from BOM |  | Connector_PinHeader_2.00mm:PinHeader_1x02_P2.00mm_Vertical | USB HOST PWR
JP6,OP8 | 2 | HDR 1x02 Pin |  |  |  | Connector_PinHeader_2.00mm:PinHeader_1x02_P2.00mm_Vertical | CNSLon2,USB RXEN
M1 | 1 | AES-FTDI_FT234XF_USB_UART_Module |  |  |  | AES_Library:AES-FTDI-UMFT234XF | COM2
M2 | 1 | DISPLAY |  |  |  | AES_Library:OLED-Disp-Socket-P2-8BitPI-AES
OP1 | 1 | AES-Opt_1_of_2 |  |  |  | Connector_PinHeader_2.00mm:PinHeader_1x03_P2.00mm_Vertical | CLKh RST
OP2,OP3 | 2 | AES-Option_A-B |  |  |  | Connector_PinHeader_2.00mm:PinHeader_1x03_P2.00mm_Vertical | HDSK IN,HDSK OUT
OP4,OP6 | 2 | CONN 2x3 HDR |  |  |  | AES_Library:PinHeader_2x03_AB_2mm-AES | IOCLK FUNC,ZCLK FUNC
OP5 | 1 | HDR 02x03 |  |  |  | AES_Library:PinHeader_2x03_AB_2mm-AES | RAM|50/50|ROM
OP7 | 1 | HDR 2x02 2mm |  |  |  | AES_Library:PinHeader_2x02_AB_2mm-AES | CTC3 CLK
Q1 | 1 | DMG2305UX |  |  |  | AES_Library:DMG2305-SOT-23-3-AES
R1,R2,R3,R4 | 4 | 510 |  |  |  | Resistor_SMD:R_0805_2012Metric
R5,R14 | 2 | 27.4 |  |  |  | Resistor_SMD:R_0805_2012Metric
R6,R8,R17,R22,R26,R28,R30,R31,R32,R33 | 10 | 10k |  |  |  | Resistor_SMD:R_0805_2012Metric
R7,R9,R10,R11,R12,R13,R15,R16,R18,R19,R21 | 11 | 22 |  |  |  | Resistor_SMD:R_0805_2012Metric
R20 | 1 | 7.5k |  |  |  | Resistor_SMD:R_0805_2012Metric
R23,R24,R25 | 3 | 20k |  |  |  | Resistor_SMD:R_0805_2012Metric
R27 | 1 | 0 |  |  |  | Resistor_SMD:R_0805_2012Metric
R29 | 1 | 33.2k |  |  |  | Resistor_SMD:R_0805_2012Metric
RN1 | 1 | 20k |  |  |  | Resistor_THT:R_Array_SIP9
RN2,RN3,RN4,RN5,RN6,RN7,RN8 | 7 | 10k |  |  |  | Resistor_THT:R_Array_SIP9
RV1 | 1 | 10k |  |  |  | AES_Library:Pot-Molence-Amazon-PCB-AES | CONTRAST
SD1 | 1 | MicroSD-Socket |  |  |  | AES_Library:AES-SDCard-GCT_MEM2075-00-140-01-A
SW1 | 1 | SW_Push |  |  |  | AES_Library:AES-SW_PUSH_SMD_1P1T_NO_6x6mm | RESET
SW2 | 1 | SW Toggle PCB |  |  |  | AES_Library:SW-SPDT-PCB-TGL-RA-AES | POWER
U1 | 1 | 12MHz |  |  |  | Package_DIP:DIP-14_W7.62mm_LongPads
U2,U11,U32 | 3 | 74AHCT74DR |  |  |  | Package_SO:SOIC-14_3.9x8.7mm_P1.27mm
U3 | 1 | MIC2775 |  |  |  | Package_TO_SOT_SMD:SOT-23-5
U4,U5 | 2 | 74AHCT08 |  |  |  | Package_SO:SOIC-14_3.9x8.7mm_P1.27mm
U6,U8 | 2 | 74AHCT00 |  |  |  | Package_SO:SOIC-14_3.9x8.7mm_P1.27mm
U7 | 1 | 74AHCT02 |  |  |  | Package_SO:SOIC-14_3.9x8.7mm_P1.27mm
U9,U38 | 2 | 74AHCT32 |  |  |  | Package_SO:SOIC-14_3.9x8.7mm_P1.27mm
U10,U42 | 2 | 74F260 |  |  |  | Package_SO:SOIC-14_3.9x8.7mm_P1.27mm
U12,U16 | 2 | 74ACT138D |  |  |  | Package_SO:SOIC-16_3.9x9.9mm_P1.27mm | I/O Decode,Mem Decode
U13 | 1 | Z80CPU |  |  |  | Package_DIP:DIP-40_W15.24mm_Socket_LongPads
U14,U29 | 2 | 74F27 |  |  |  | Package_SO:SOIC-14_3.9x8.7mm_P1.27mm
U15 | 1 | SRAM 8K/32K |  |  |  | Package_SO:SOJ-28_7.62x18.415mm_P1.27mm | PAGE REG
U17 | 1 | 74AHC541NS |  |  |  | Package_SO:SO-20_5.3x12.6mm_P1.27mm
U18,U25,U26,U27,U30 | 5 | 74AHCT245NS |  |  |  | Package_SO:SO-20_5.3x12.6mm_P1.27mm
U19,U34 | 2 | 74ACT10 |  |  |  | Package_SO:SOIC-14_3.9x8.7mm_P1.27mm
U20 | 1 | 74ACT11 |  |  |  | Package_SO:SOIC-14_3.9x8.7mm_P1.27mm
U21 | 1 | AS6C4008 |  |  |  | Package_DIP:DIP-32_W15.24mm_Socket_LongPads | RAM 512K
U22 | 1 | SST39SF040 |  |  |  | Package_DIP:DIP-32_W15.24mm_Socket_LongPads | ROM 512K
U23,U24 | 2 | 74AHCT244NS |  |  |  | Package_SO:SO-20_5.3x12.6mm_P1.27mm
U28 | 1 | 74HCT273NS |  |  |  | Package_SO:SO-20_5.3x12.6mm_P1.27mm
U31 | 1 | 3.6864MHz |  |  |  | Package_DIP:DIP-14_W7.62mm_LongPads
U33 | 1 | Z84C30 CTC |  |  |  | Package_DIP:DIP-28_W15.24mm_LongPads
U35 | 1 | Z84C42 SIO/2 |  |  |  | Package_DIP:DIP-40_W15.24mm_Socket_LongPads
U36 | 1 | SN74LVC8T245NS |  |  |  | Package_SO:SO-24_5.3x15mm_P1.27mm
U37 | 1 | 74AHCT1G02 |  |  |  | Package_TO_SOT_SMD:SOT-23-5
U39 | 1 | 74AHCT04 |  |  |  | Package_SO:SOIC-14_3.9x8.7mm_P1.27mm
U40,U47 | 2 | 74LVC1G06W |  |  |  | Package_TO_SOT_SMD:SOT-23-5
U41 | 1 | 74LV21 |  |  |  | Package_SO:SOIC-14_3.9x8.7mm_P1.27mm
U43,U44 | 2 | 74LVC125AS |  |  |  | Package_SO:SOIC-14_3.9x8.7mm_P1.27mm | 5-3V,ZCLK=CLKf,ZCLK=CLKh
U45 | 1 | ~ |  |  |  | AES_Library:RP2040_WS-AES
U46 | 1 | MAX232/ST232 |  |  |  | Package_SO:SOIC-16_3.9x9.9mm_P1.27mm

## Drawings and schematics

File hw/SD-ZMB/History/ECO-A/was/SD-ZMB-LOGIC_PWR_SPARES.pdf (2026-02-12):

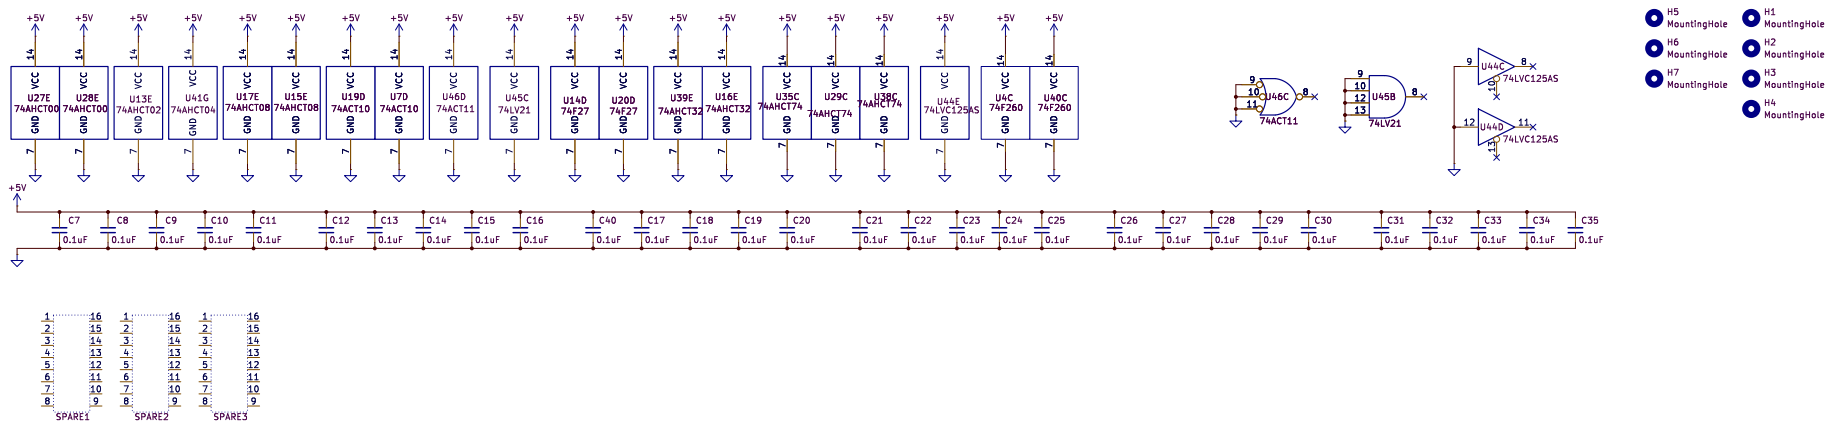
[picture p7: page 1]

SilkyDESIGN
File: logic_pwr_spr.kicad_sch Sheet: /LOGIC_PWR_SPARES/
Id: 4/4 Title: Logic Power & Spares

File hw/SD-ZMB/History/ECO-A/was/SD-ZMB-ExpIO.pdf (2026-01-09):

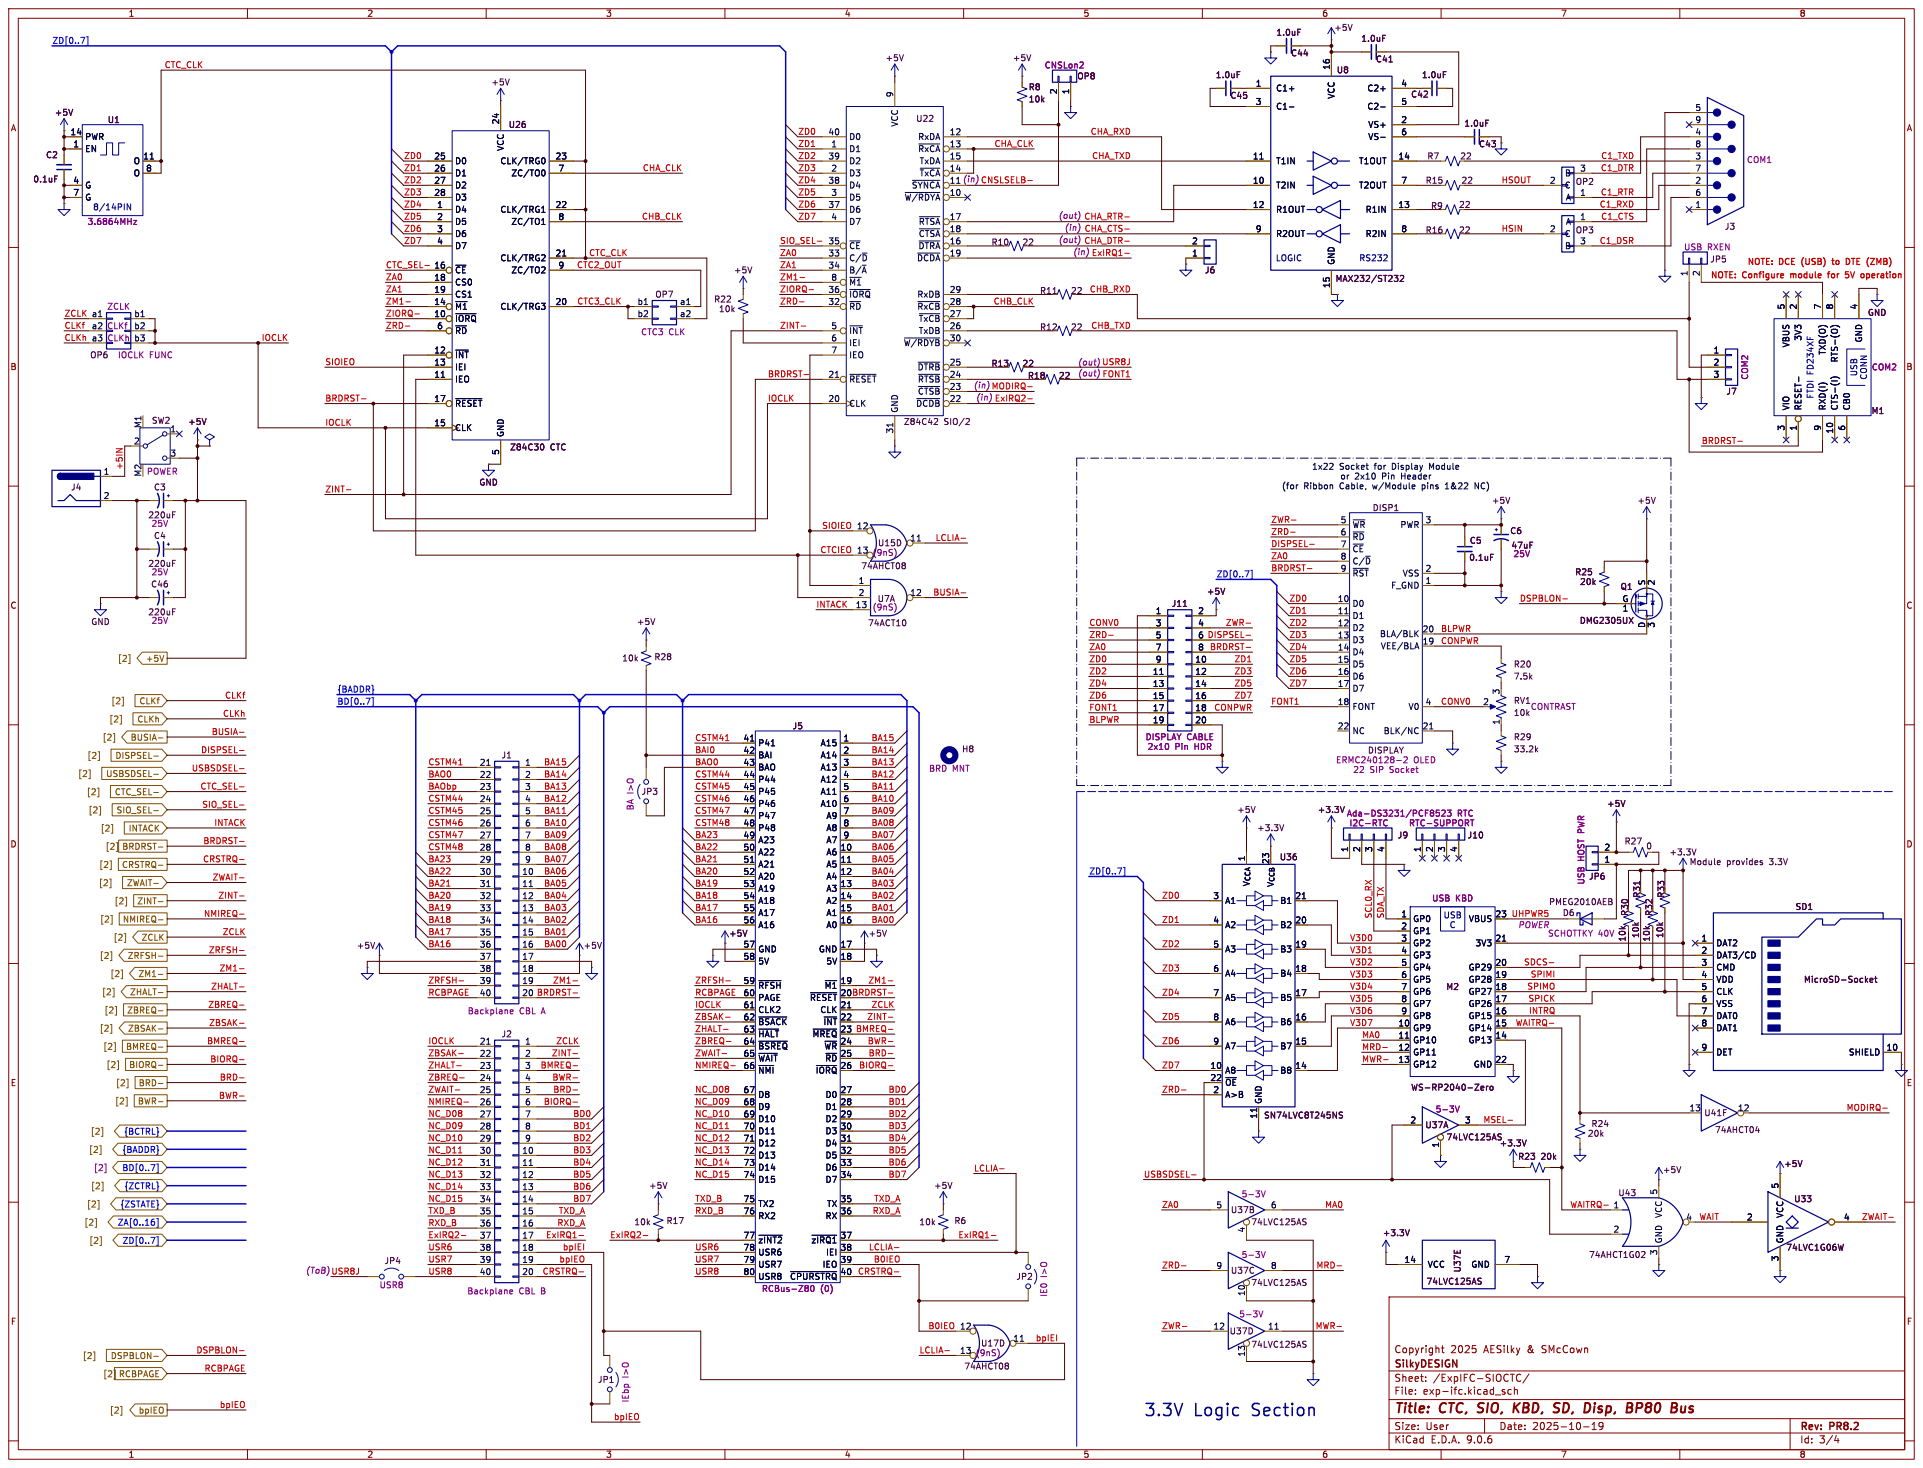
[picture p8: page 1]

9 GND 31 RxDA 12 ~{RxCA}13 TxDA 15 ~{TxCA}14 ~{SYNCA}11 ~{W/RDYA}10 ~{RTSA}17 ~{CTSA}18 ~{DTRA}16 ~{DCDA}19 RxDB 29 ~{RxCB}28 ~{TxCB}27 TxDB 26 ~{W/RDYB} 30 ~{DTRB}25 ~{RTSB}24 ~{CTSB}23 ~{DCDB}22 U22 Z84C42 SIO/2 C

5 CLK/TRG0 23 ZC/TO0 7 CLK/TRG1 22 ZC/TO1 8 CLK/TRG2 21 ZC/TO2 9 CLK/TRG3 20 U1

5 CLK/TRG0 23 ZC/TO0 7 CLK/TRG1 22 ZC/TO1 8 CLK/TRG2 21 ZC/TO2 9 CLK/TRG3 20 U26 Z84C30 CTC

JP5 USB RXEN
NOTE: DCE (USB) to DTE (ZMB) NOTE: Configure module for 5V operation

1x22 Socket for Display Module
or 2x10 Pin Header
J11 DISPLAY CABLE

[2] CLKf
[2] CLKh
[2] BUSIA-
[2] DISPSEL-
ZINT- ZWAIT- NMIREQ- ZHALT- ZM1- ZRFSH- BRDRST- SIO_SEL- CTC_SEL-
INTACK CRSTRQ- ZCLK

JP6 USB HOST PWR
3V3 21 GP29 20 GP28 19 GP27 18 GP26 17 GP15 16 GP14 15 GP13 14 GND 22 M2 WS-RP2040-Zero USB KBD

5V 58 ~{RFSH} 59 PAGE 60 CLK2 61 ~{BSACK} 62 ~{HALT} 63 ~{BSREQ} 64 ~{WAIT} 65 ~{NMI} 66 D8 67 D9 68 D10 69 D11 70 D12 71 D13 72 D14 73 D15 74 TX2 75 RX2 76 ~{zINT2} 77 USR6 78 USR7 79 USR8 80
ZBSAK- NC_D09 ZWAIT- ZHALT- NMIREQ-

5V 18 ~{M1}19 ~{RESET} 20 CLK 21 ~{INT} 22 ~{MREQ} 23 ~{WR} 24 ~{RD} 25 ~{IORQ} 26 D0 27 D1 28 D2 29 D3 30 D4 31 D5 32 D6 33 D7 34 TX 35 RX 36 ~{zIRQ1}37

SilkyDESIGN
File: exp-ifc.kicad_sch Sheet: /ExpIFC-SIOCTC/
Id: 3/4 Title: CTC, SIO, KBD, SD, Disp, BP80 Bus

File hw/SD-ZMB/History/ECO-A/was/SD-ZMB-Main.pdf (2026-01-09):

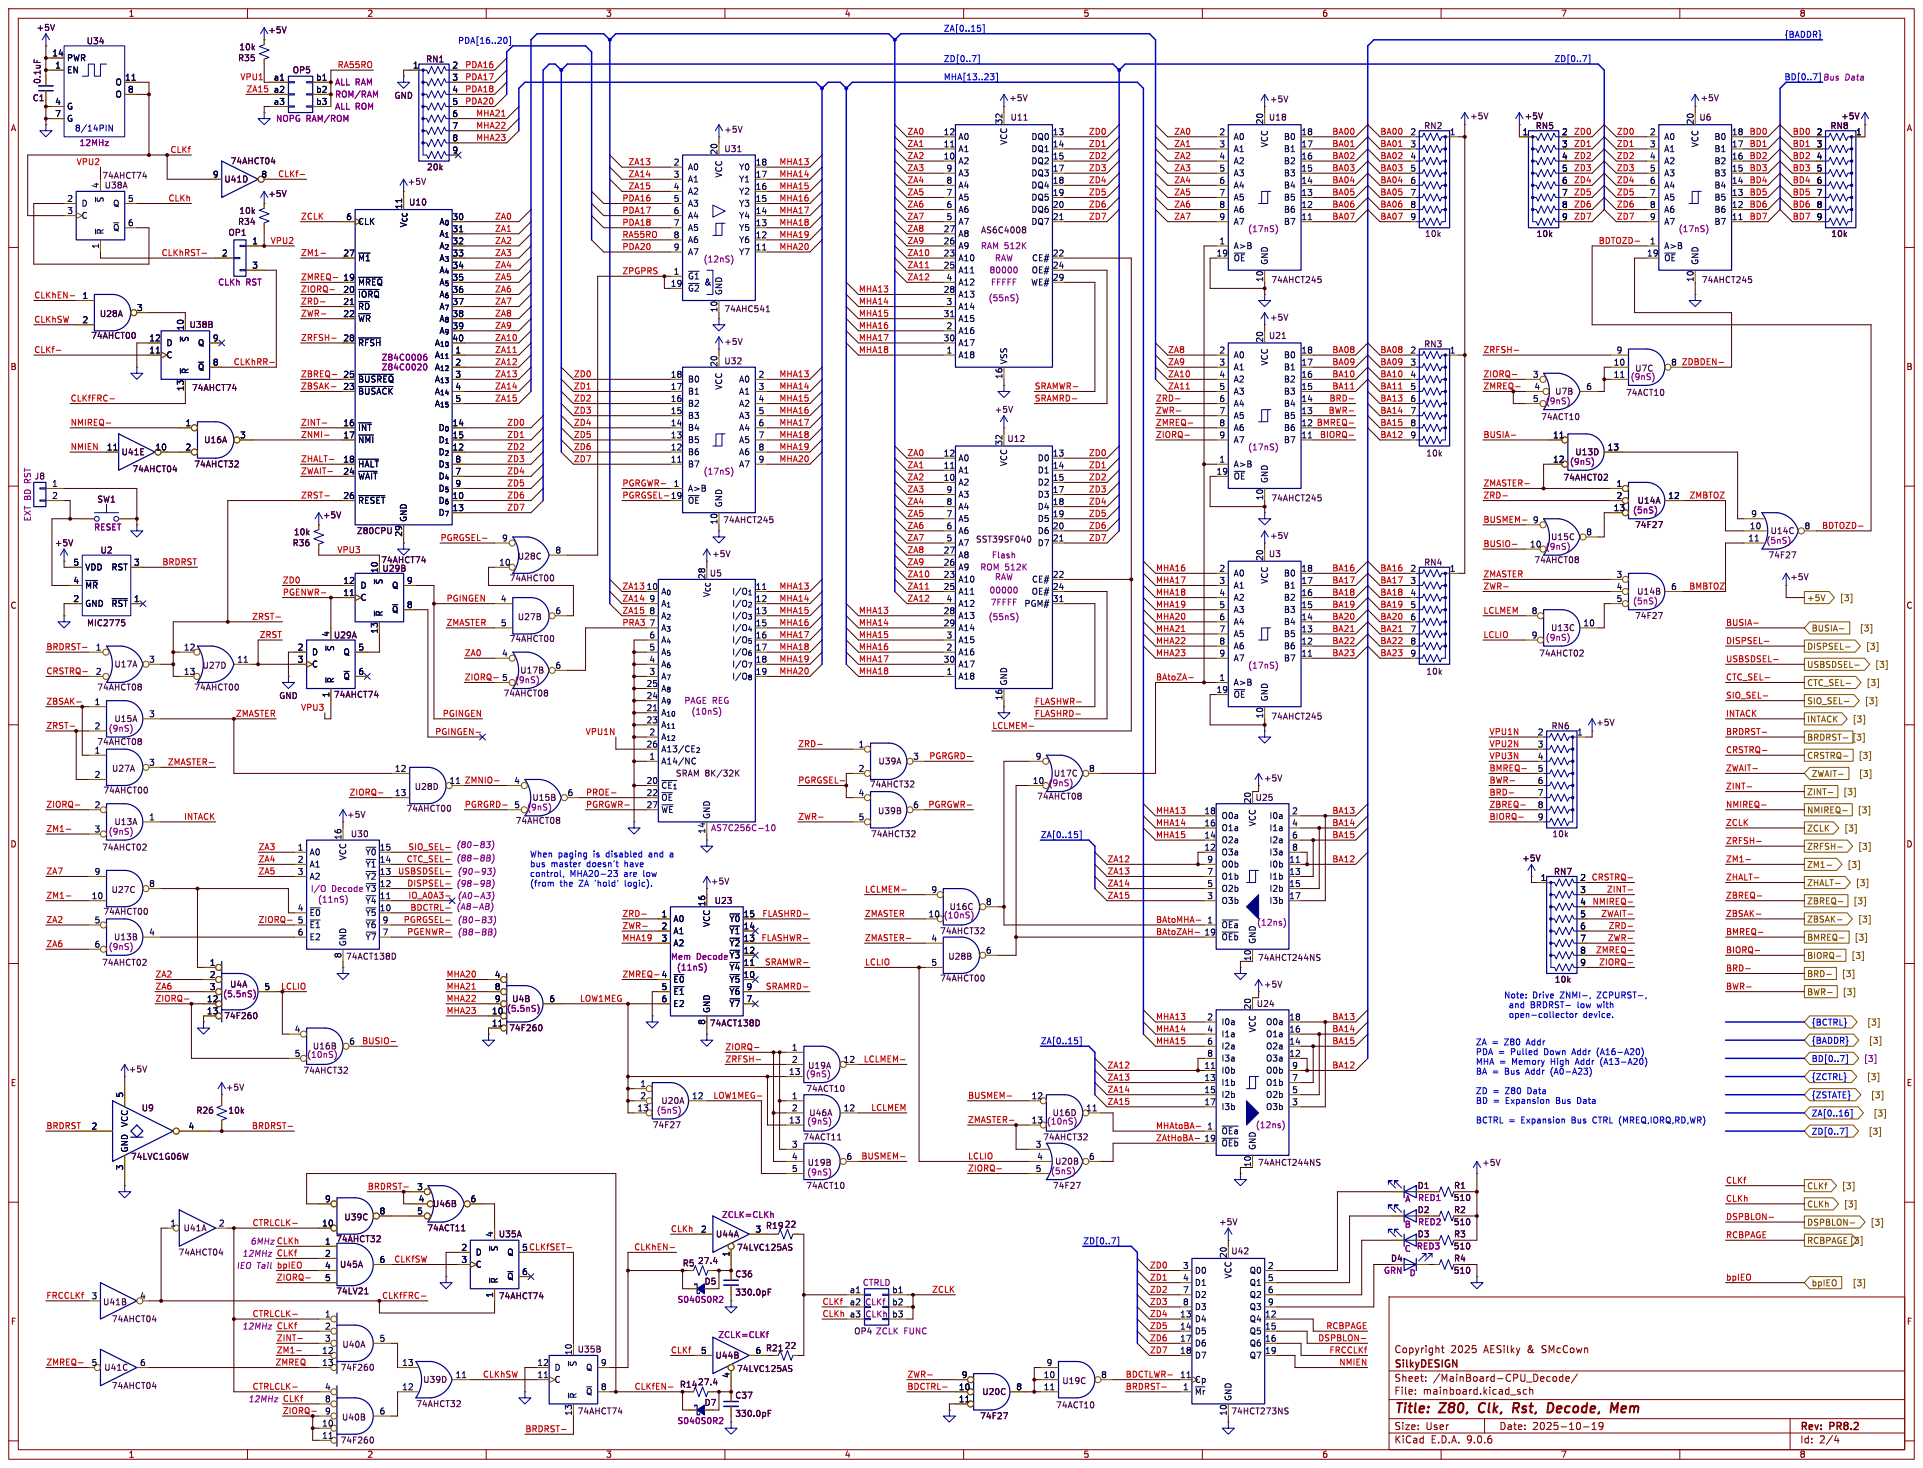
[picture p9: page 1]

bus master doesn't have

CLKfFRC- ZM1- ZINT- 12MHz CLKf CTRLCLK- ZMREQ- FRCCLKf

SilkyDESIGN
File: mainboard.kicad_sch Sheet: /MainBoard-CPU_Decode/
Id: 2/4 Title: Z80, Clk, Rst, Decode, Mem

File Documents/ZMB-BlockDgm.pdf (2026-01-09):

# MMU & Memory

## (64KB Logical : 2MB Physical)

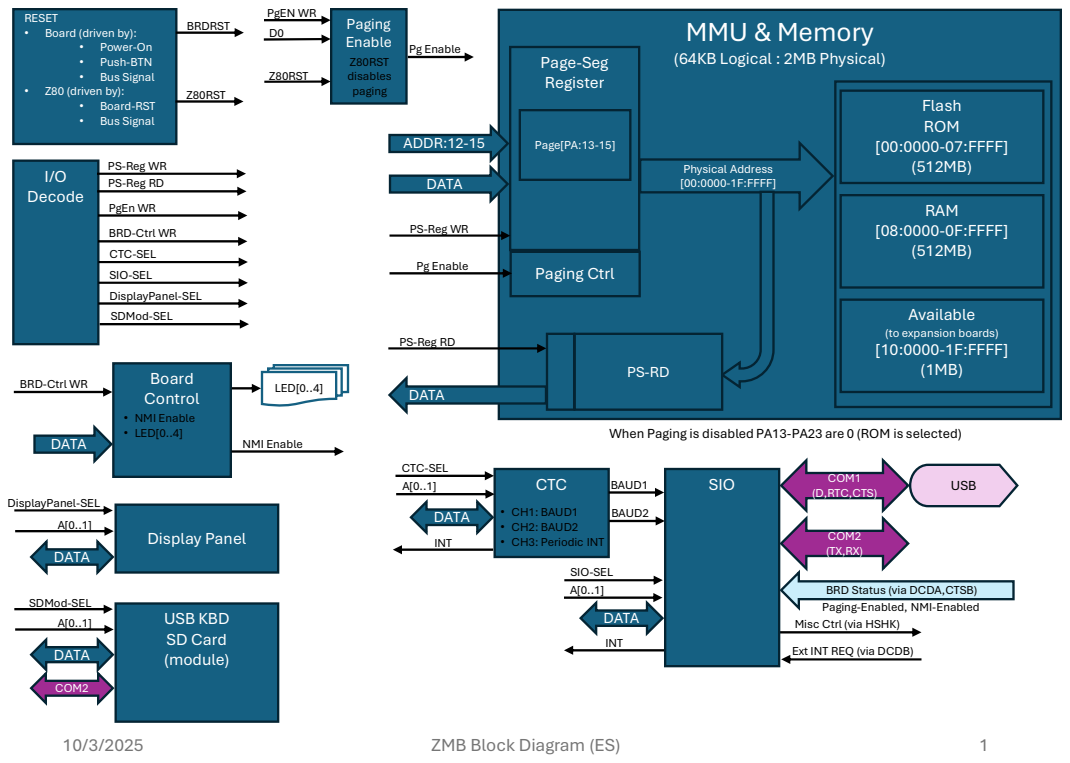
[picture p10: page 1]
RESET; Board (driven by): •; Power-On; • Push-BTN; Bus Signal •; Z80 (driven by): •; Board-RST; • Bus Signal; ZMB Block Diagram (ES); BRDRST; Z80RST; Display Panel; DisplayPanel-SEL A[0..1]; DATA; CTC; • CH1: BAUD1 • CH2: BAUD2 • CH3: Periodic INT; BAUD1; BAUD2; CTC-SEL; USB; INT; SIO; COM1 (D,RTC,CTS); COM2 (TX,RX); Page-Seg Register; Page[PA:13-15]; Flash ROM [00:0000-07:FFFF] (512MB); RAM [08:0000-0F:FFFF] (512MB); Available (to expansion boards) [10:0000-1F:FFFF] (1MB)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

PS-Reg WR
PS-Reg RD
PgEn WR
BRD-Ctrl WR
CTC-SEL
SIO-SEL
DisplayPanel-SEL
SDMod-SEL

Paging Ctrl Pg Enable

When Paging is disabled PA13-PA23 are 0 (ROM is selected)

DATA
Ext INT REQ (via DCDB) INT

BRD Status (via DCDA,CTSB)
Paging-Enabled, NMI-Enabled
Misc Ctrl (via HSHK)

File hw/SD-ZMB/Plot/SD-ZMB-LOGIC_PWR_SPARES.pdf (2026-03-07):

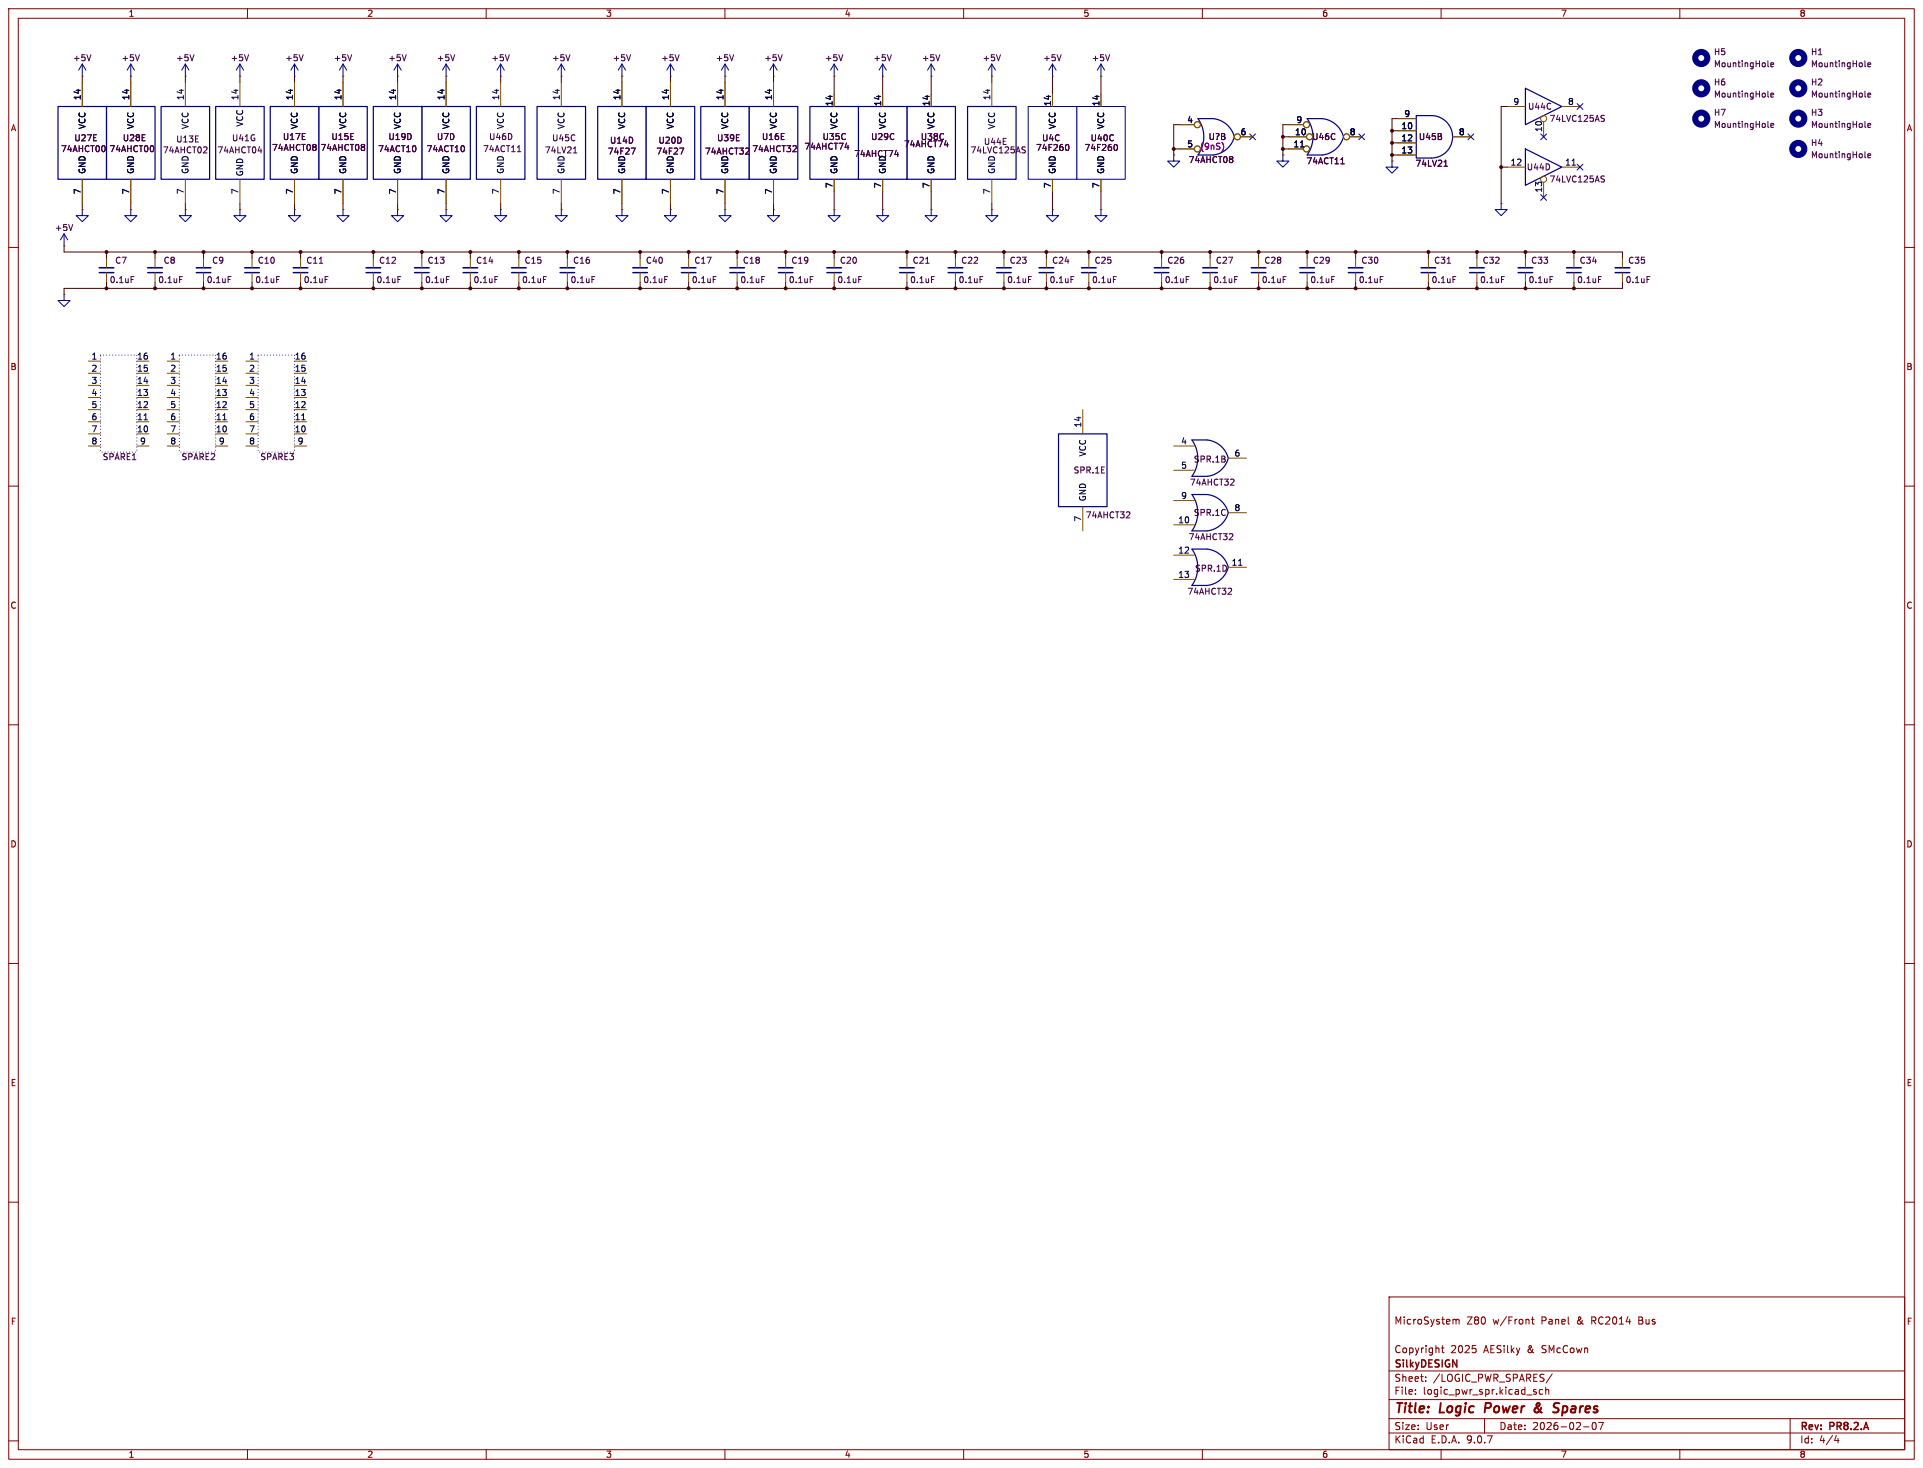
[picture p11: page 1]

SilkyDESIGN
File: logic_pwr_spr.kicad_sch Sheet: /LOGIC_PWR_SPARES/
Id: 4/4 Title: Logic Power & Spares

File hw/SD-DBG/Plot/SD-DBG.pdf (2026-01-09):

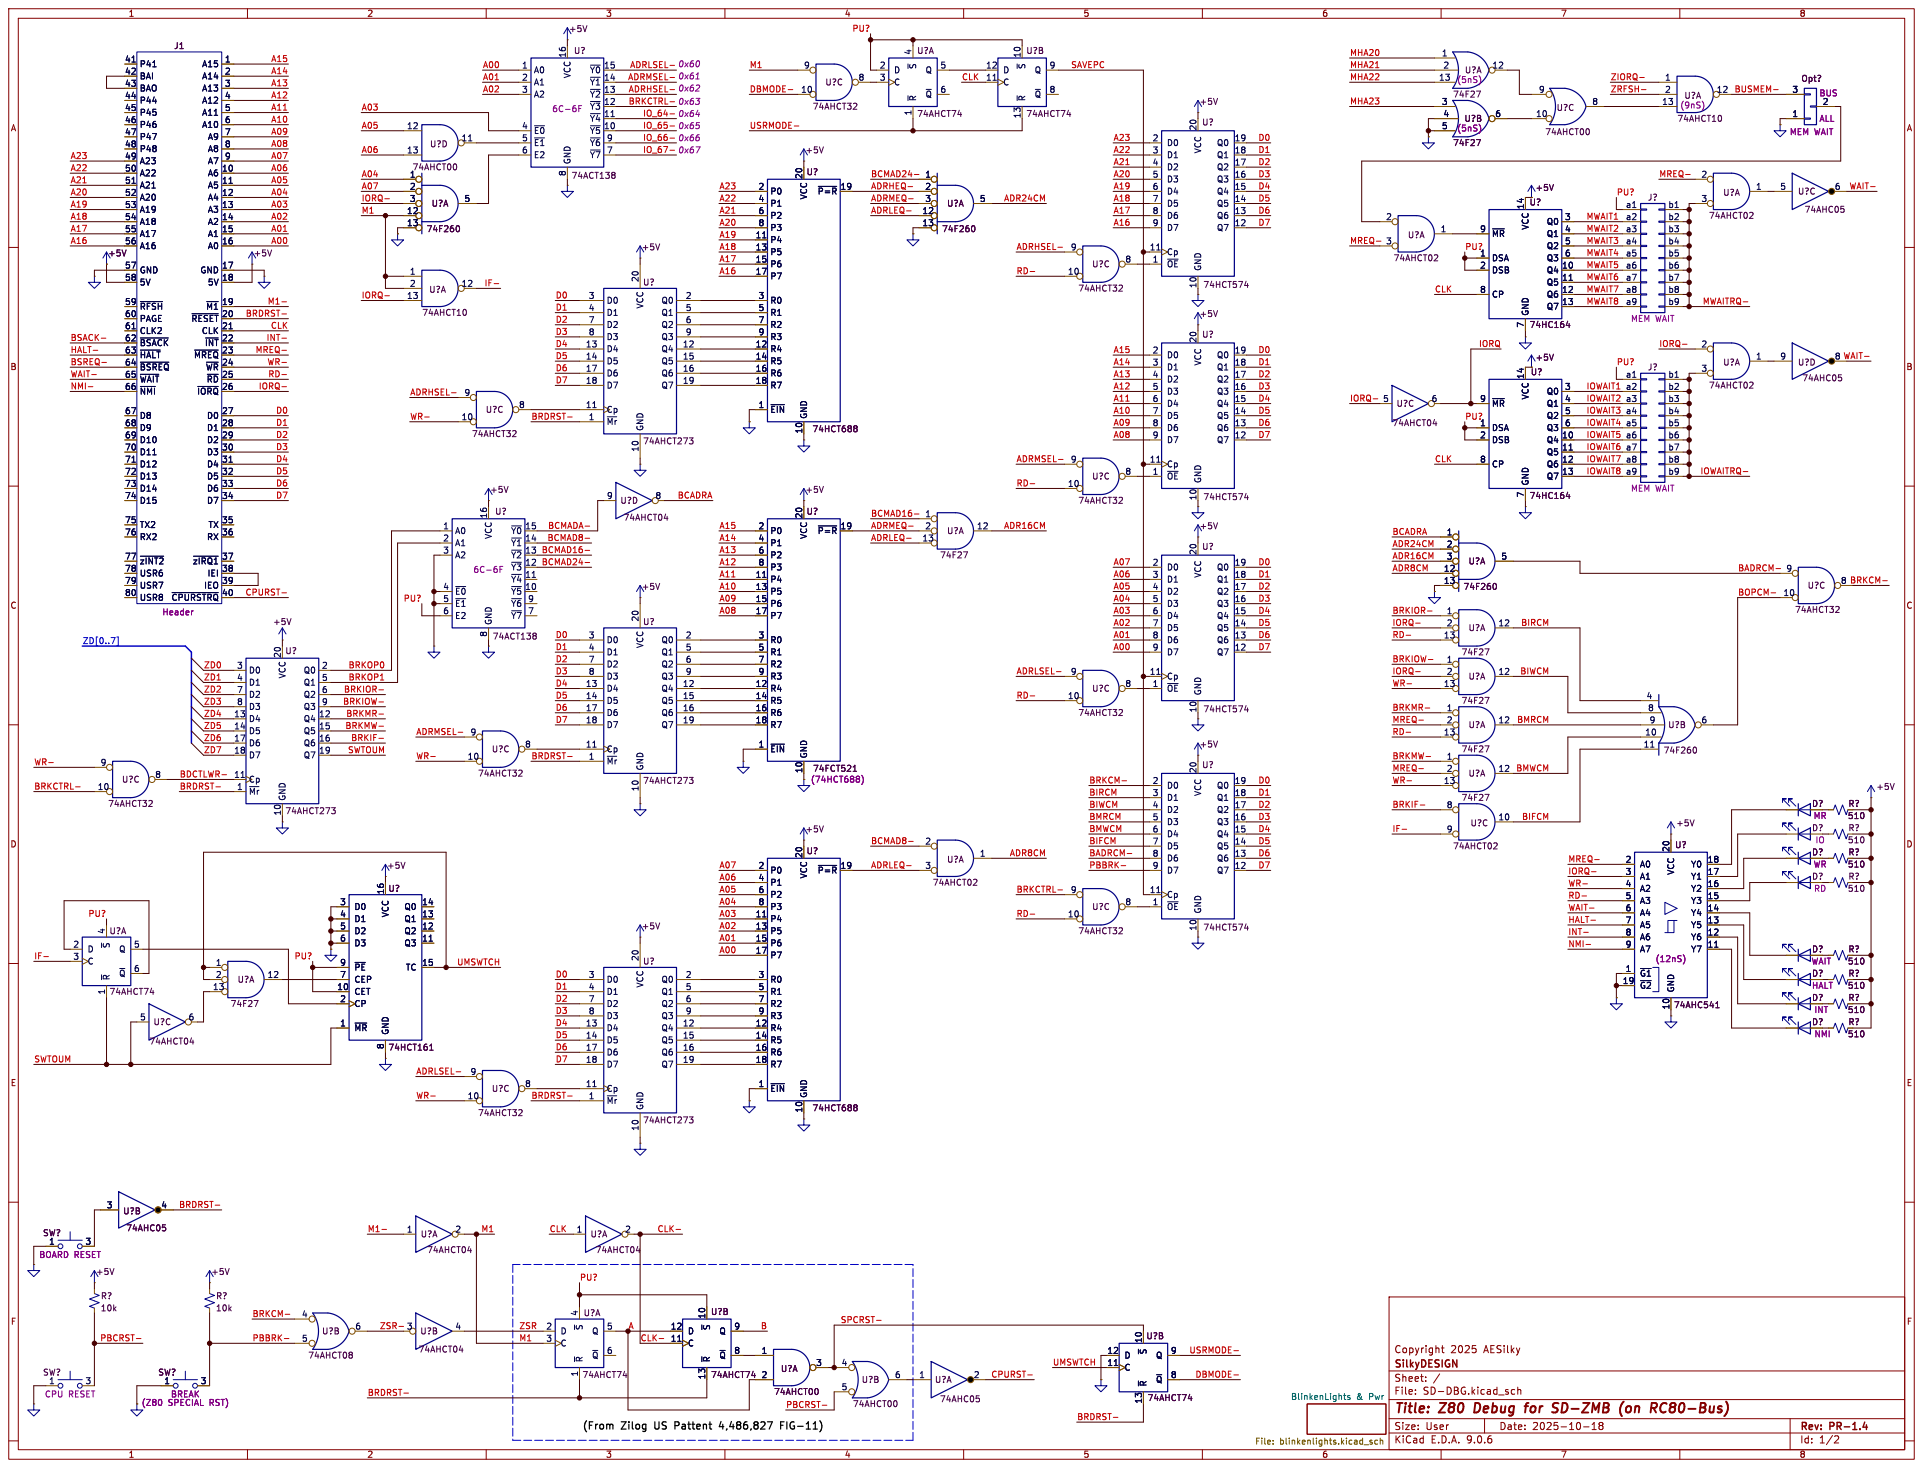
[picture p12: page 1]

IO_65- 0x65 BRKCTRL- 0x63 ADRMSEL- 0x61 ADRHSEL- 0x62 WR- ADRHSEL-
IORQ- A06 A07 A04 A03 A05

2 Opt? MEM WAIT ALL BUS

Opt? MEM WAIT ALL BUS

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

74AHCT32 +5V
5V 18 ~{M1}19 ~{RESET} 20 CLK 21 ~{INT} 22 ~{MREQ} 23 ~{WR} 24 ~{RD} 25 ~{IORQ} 26 D0 27 D1 28 D2 29 D3 30 D4 31 D5 32 D6 33 D7 34 TX 35 RX 36 ~{zIRQ1}37

INT- BRDRST- CLK RD- MREQ- WR-

Id: 1/2 Title: Z80 Debug for SD-ZMB (on RC80-Bus) File: SD-DBG.kicad_sch Sheet: / SilkyDESIGN

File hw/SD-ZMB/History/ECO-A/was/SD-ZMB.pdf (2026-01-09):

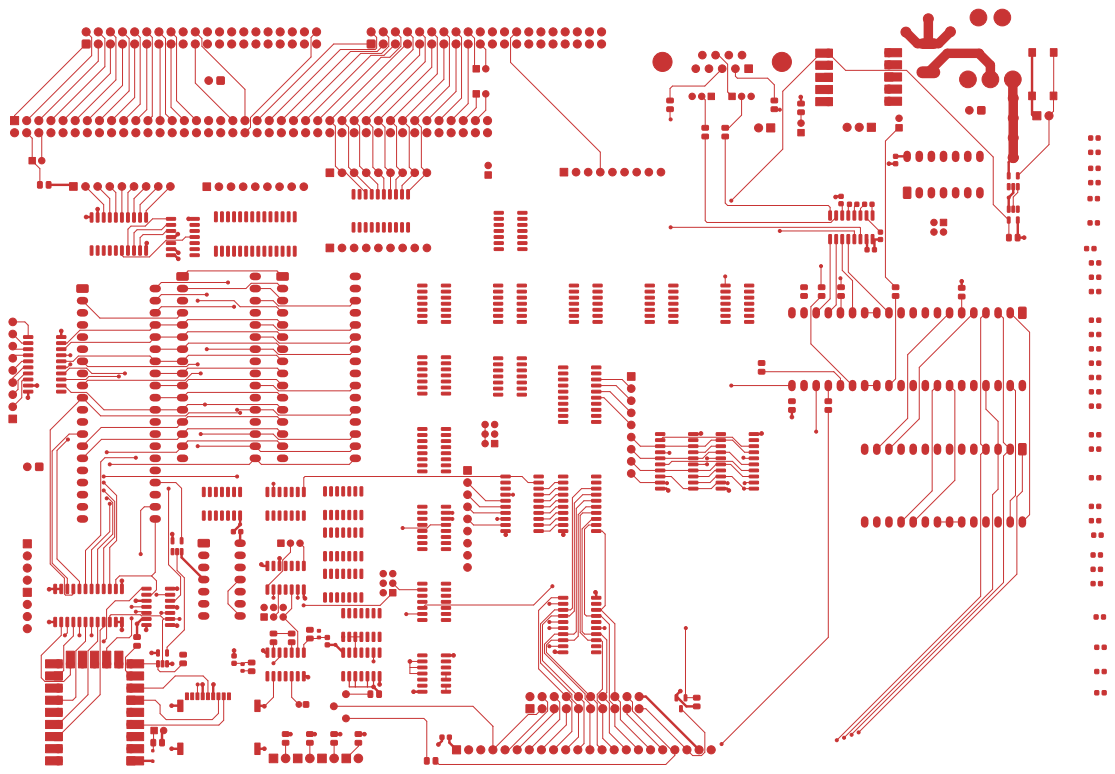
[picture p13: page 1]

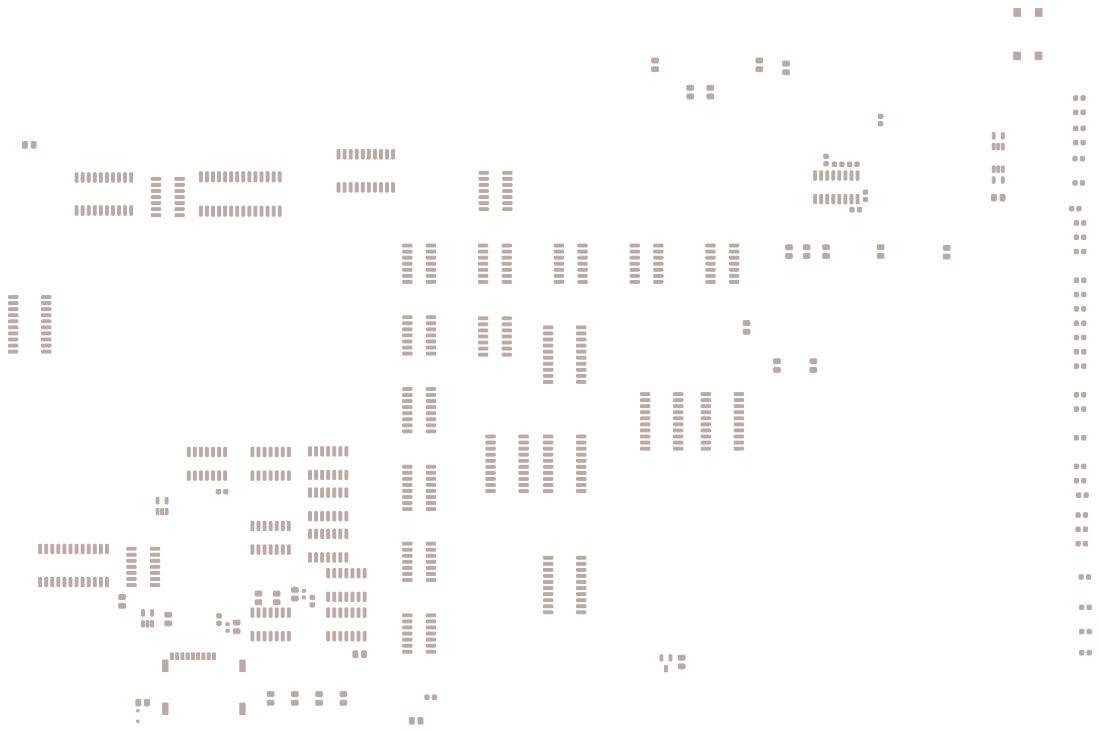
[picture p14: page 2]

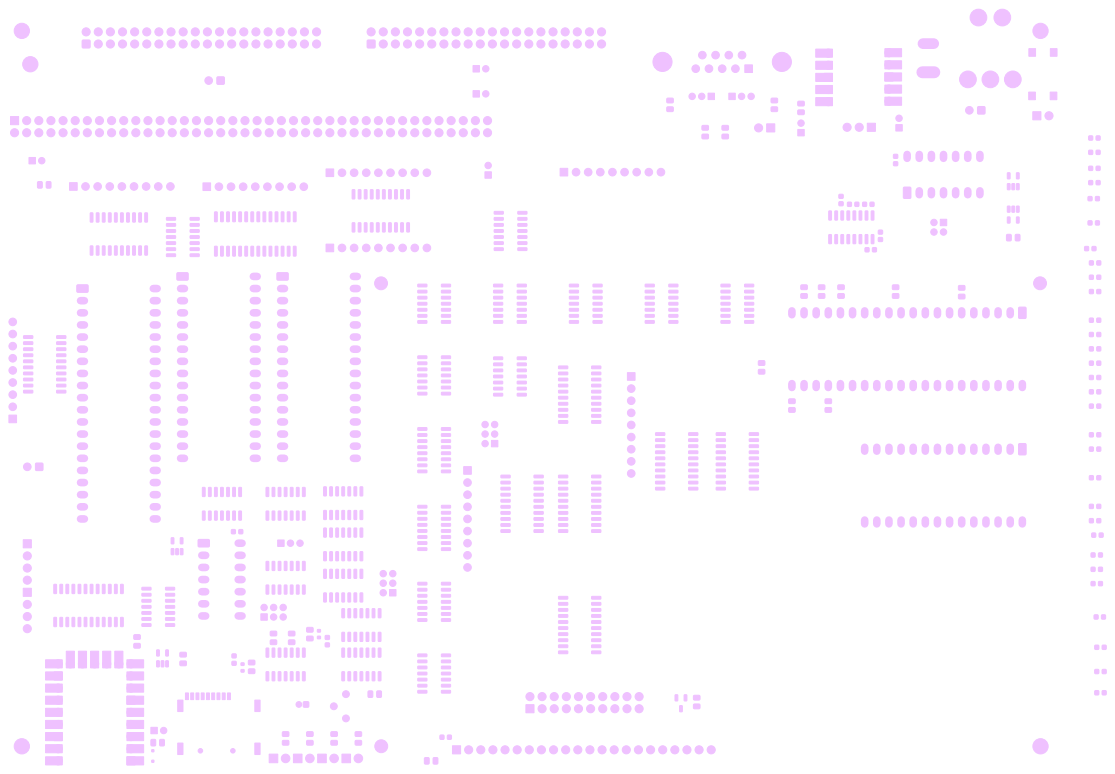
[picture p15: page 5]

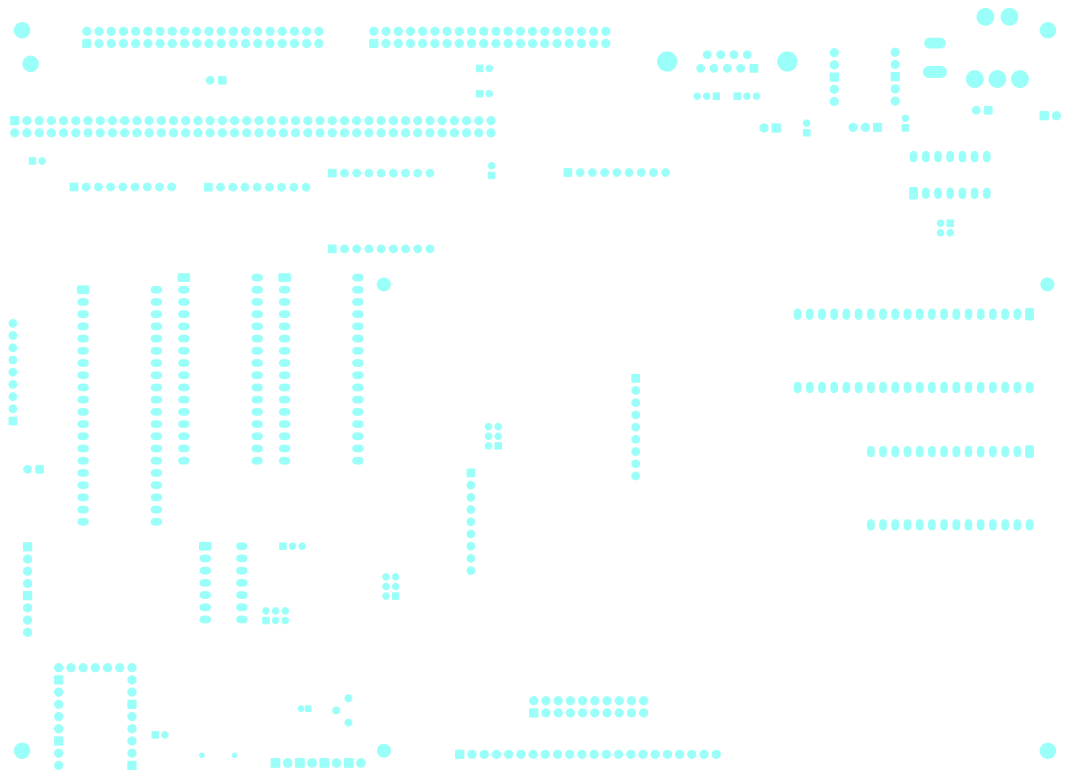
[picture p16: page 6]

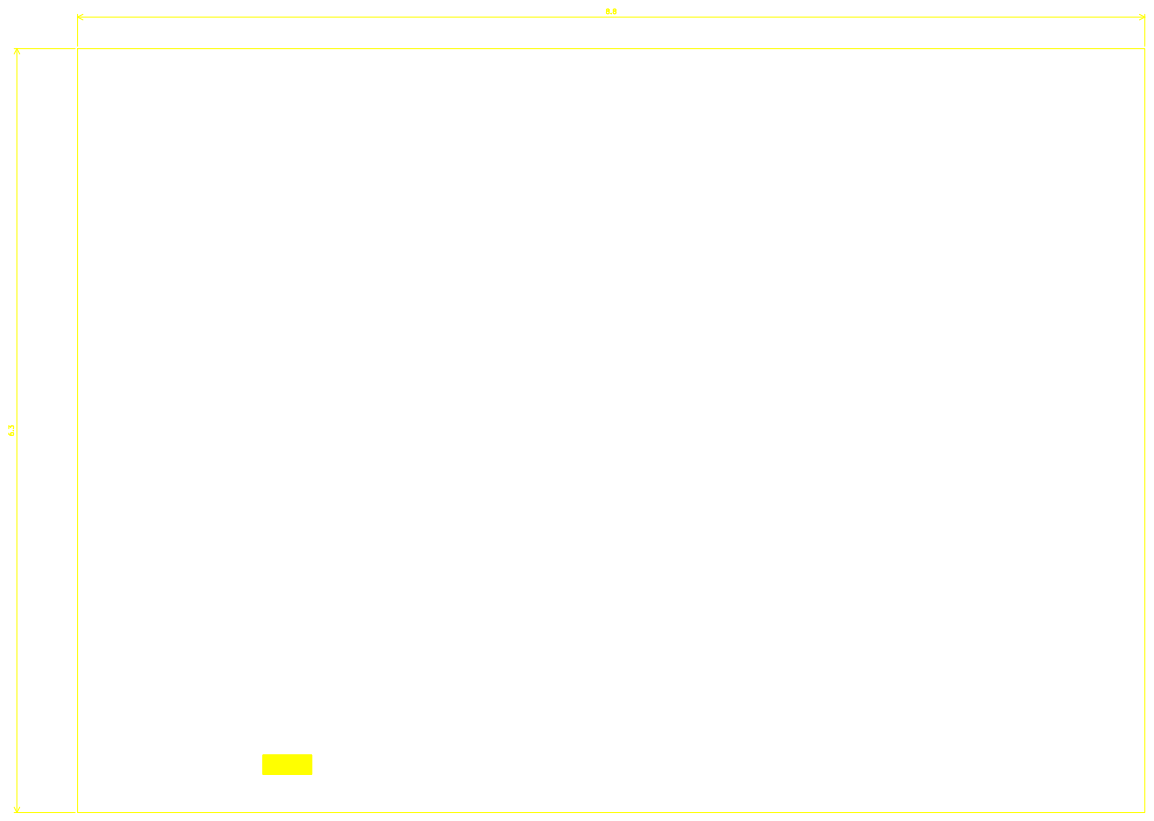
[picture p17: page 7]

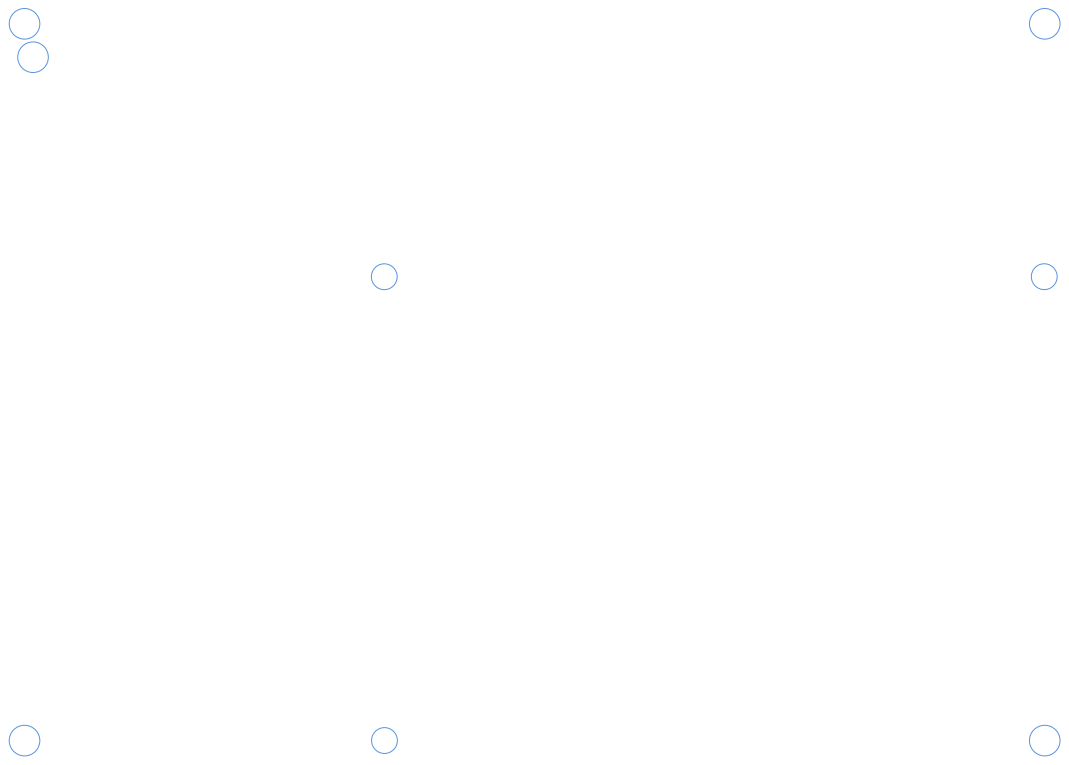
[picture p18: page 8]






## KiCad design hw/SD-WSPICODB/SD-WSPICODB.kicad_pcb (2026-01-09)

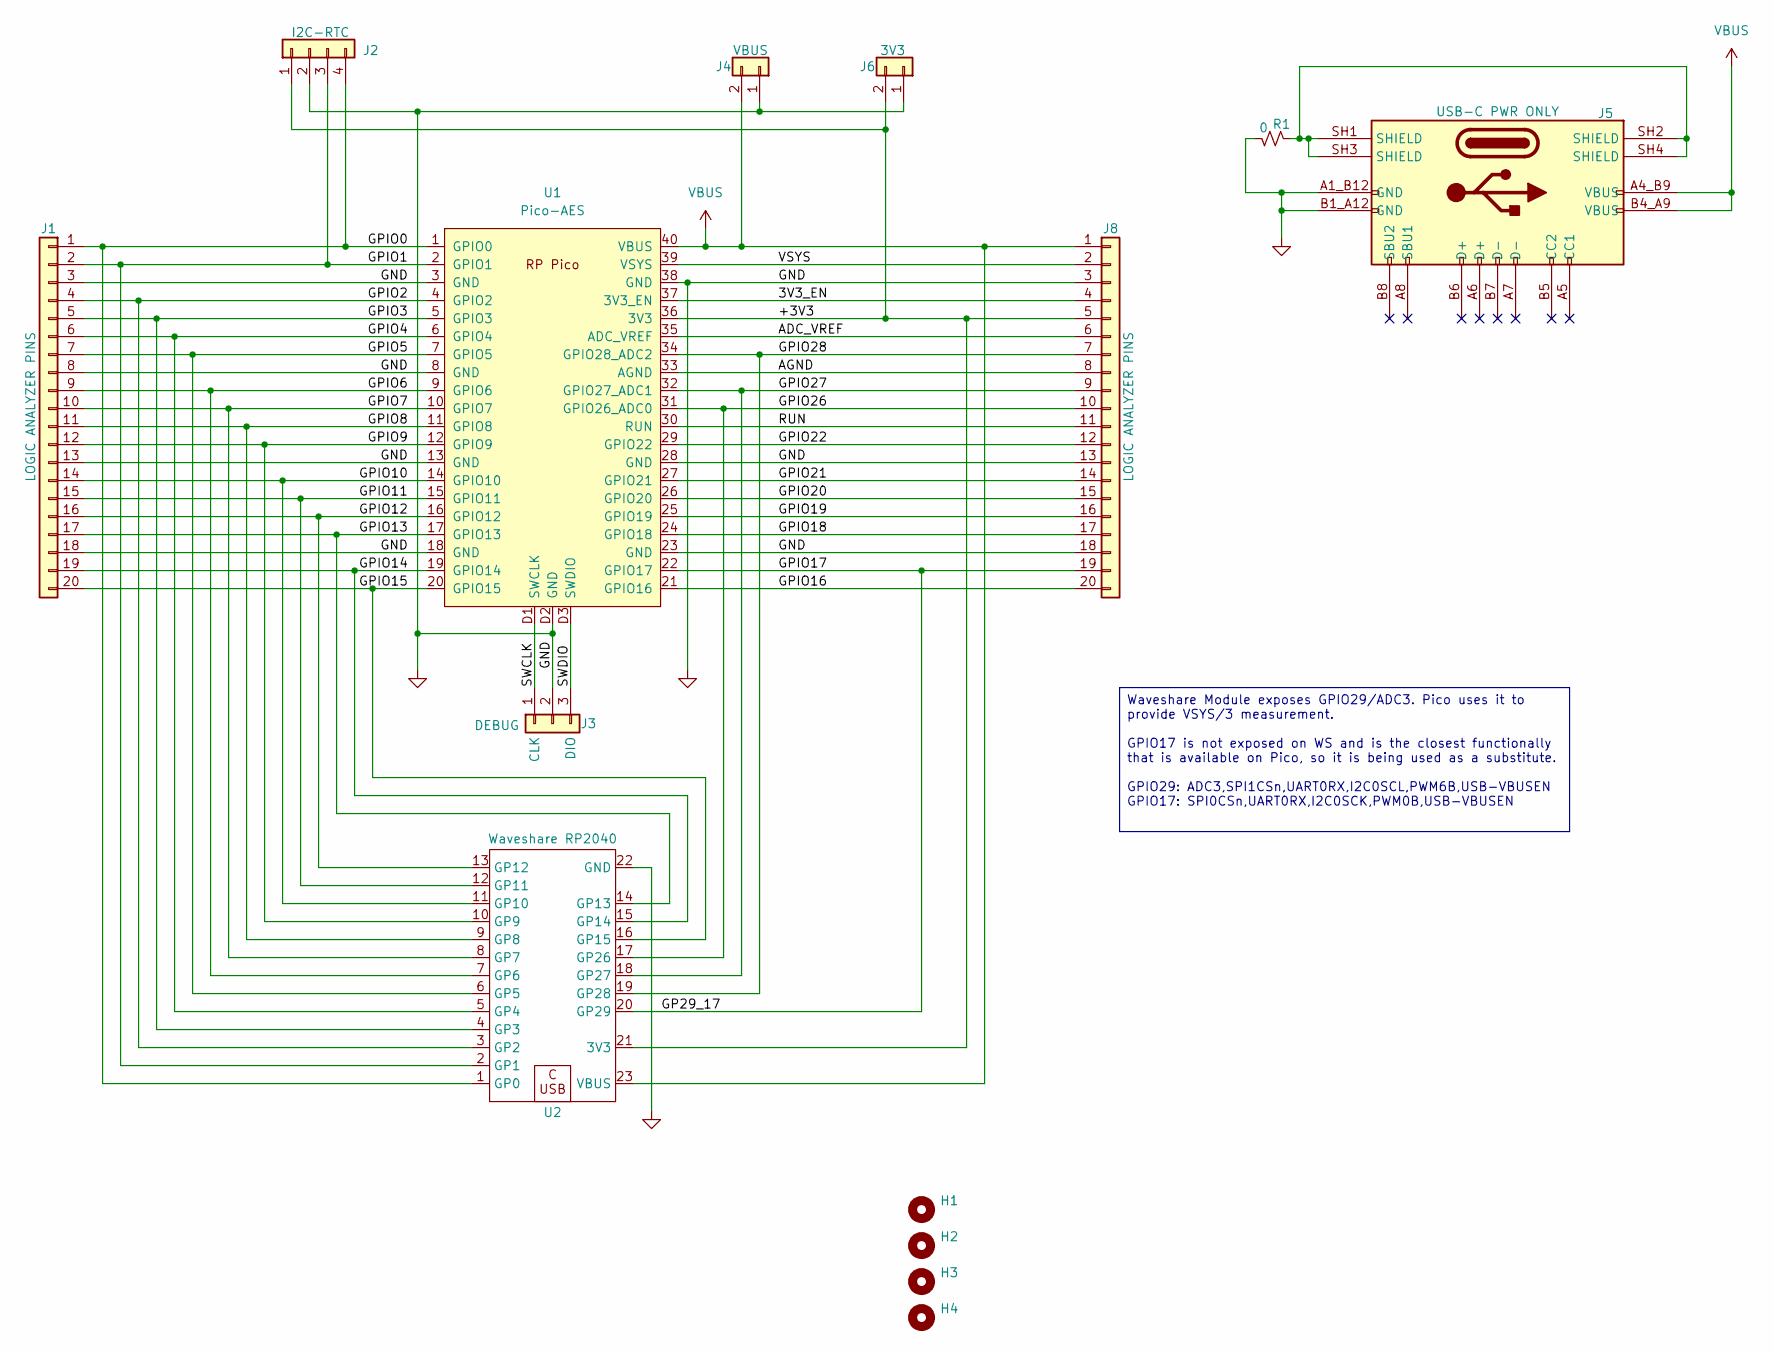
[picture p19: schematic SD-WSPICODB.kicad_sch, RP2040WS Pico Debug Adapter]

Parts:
H1, H2, H3, H4: MountingHole; MountingHole_2.2mm_M2
J1, J8: CONN 1x20 HDR; PinHeader_1x20_P2.54mm_Vertical
J2: HDR 1x04 Socket; PinSocket_1x04_P2.54mm_Vertical
J3: CONN 1x3 HDR; PinHeader_1x03_P2.54mm_Vertical
J4, J6: CONN 1x2 HDR; PinHeader_1x02_P2.54mm_Vertical
J5: USB-C PWR ONLY; AES-USB_C-Molex-BdTopMnt-2171790001
R1: 0; R_0805_2012Metric_Pad1.20x1.40mm_HandSolder
U1: Pico-AES; AES-RPi_Pico_SMD_TH
U2: Waveshare RP2040; RP2040_WS-AES

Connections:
/3V3_EN: J8.4, U1.37 (3V3_EN)
/+3V3: J2.1, J6.2, J8.5, U1.36 (3V3), U2.21 (3V3)
/ADC_VREF: J8.6, U1.35 (ADC_VREF)
/AGND: J8.8, U1.33 (AGND)
/GP29_17: J8.19, U1.22 (GPIO17), U2.20 (GP29)
/GPIO0: J1.1, J2.4, U1.1 (GPIO0), U2.1 (GP0)
/GPIO1: J1.2, J2.3, U1.2 (GPIO1), U2.2 (GP1)
/GPIO2: J1.4, U1.4 (GPIO2), U2.3 (GP2)
/GPIO3: J1.5, U1.5 (GPIO3), U2.4 (GP3)
/GPIO4: J1.6, U1.6 (GPIO4), U2.5 (GP4)
/GPIO5: J1.7, U1.7 (GPIO5), U2.6 (GP5)
/GPIO6: J1.9, U1.9 (GPIO6), U2.7 (GP6)
/GPIO7: J1.10, U1.10 (GPIO7), U2.8 (GP7)
/GPIO8: J1.11, U1.11 (GPIO8), U2.9 (GP8)
/GPIO9: J1.12, U1.12 (GPIO9), U2.10 (GP9)
/GPIO10: J1.14, U1.14 (GPIO10), U2.11 (GP10)
/GPIO11: J1.15, U1.15 (GPIO11), U2.12 (GP11)
/GPIO12: J1.16, U1.16 (GPIO12), U2.13 (GP12)
/GPIO13: J1.17, U1.17 (GPIO13), U2.14 (GP13)
/GPIO14: J1.19, U1.19 (GPIO14), U2.15 (GP14)
/GPIO15: J1.20, U1.20 (GPIO15), U2.16 (GP15)
/GPIO16: J8.20, U1.21 (GPIO16)
/GPIO18: J8.17, U1.24 (GPIO18)
/GPIO19: J8.16, U1.25 (GPIO19)
/GPIO20: J8.15, U1.26 (GPIO20)
/GPIO21: J8.14, U1.27 (GPIO21)
/GPIO22: J8.12, U1.29 (GPIO22)
/GPIO26: J8.10, U1.31 (GPIO26_ADC0), U2.17 (GP26)
/GPIO27: J8.9, U1.32 (GPIO27_ADC1), U2.18 (GP27)
/GPIO28: J8.7, U1.34 (GPIO28_ADC2), U2.19 (GP28)
/RUN: J8.11, U1.30 (RUN)
/SWCLK: J3.1, U1.D1 (SWCLK)
/SWDIO: J3.3, U1.D3 (SWDIO)
/VSYS: J8.2, U1.39 (VSYS)
GND: J1.3, J1.8, J1.13, J1.18, J2.2, J3.2, J4.1, J5.A1_B12 (GND), J5.B1_A12 (GND), J6.1, J8.3, J8.13, J8.18, R1.2, U1.3 (GND), U1.8 (GND), U1.13 (GND), U1.18 (GND), U1.23 (GND), U1.28 (GND), U1.38 (GND), U1.D2 (GND), U2.22 (GND)
unnamed: J5.SH1 (SHIELD), J5.SH2 (SHIELD), J5.SH3 (SHIELD), J5.SH4 (SHIELD), R1.1
VBUS: J4.2, J5.A4_B9 (VBUS), J5.B4_A9 (VBUS), J8.1, U1.40 (VBUS), U2.23 (VBUS)

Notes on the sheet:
Waveshare Module exposes GPIO29/ADC3. Pico uses it to provide VSYS/3 measurement. GPIO17 is not exposed on WS and is the closest functionally that is available on Pico, so it is being used as a substitute. GPIO29: ADC3,SPI1CSn,UART0RX,I2C0SCL,PWM6B,USB-VBUSEN GPIO17: SPI0CSn,UART0RX,I2C0SCK,PWM0B,U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

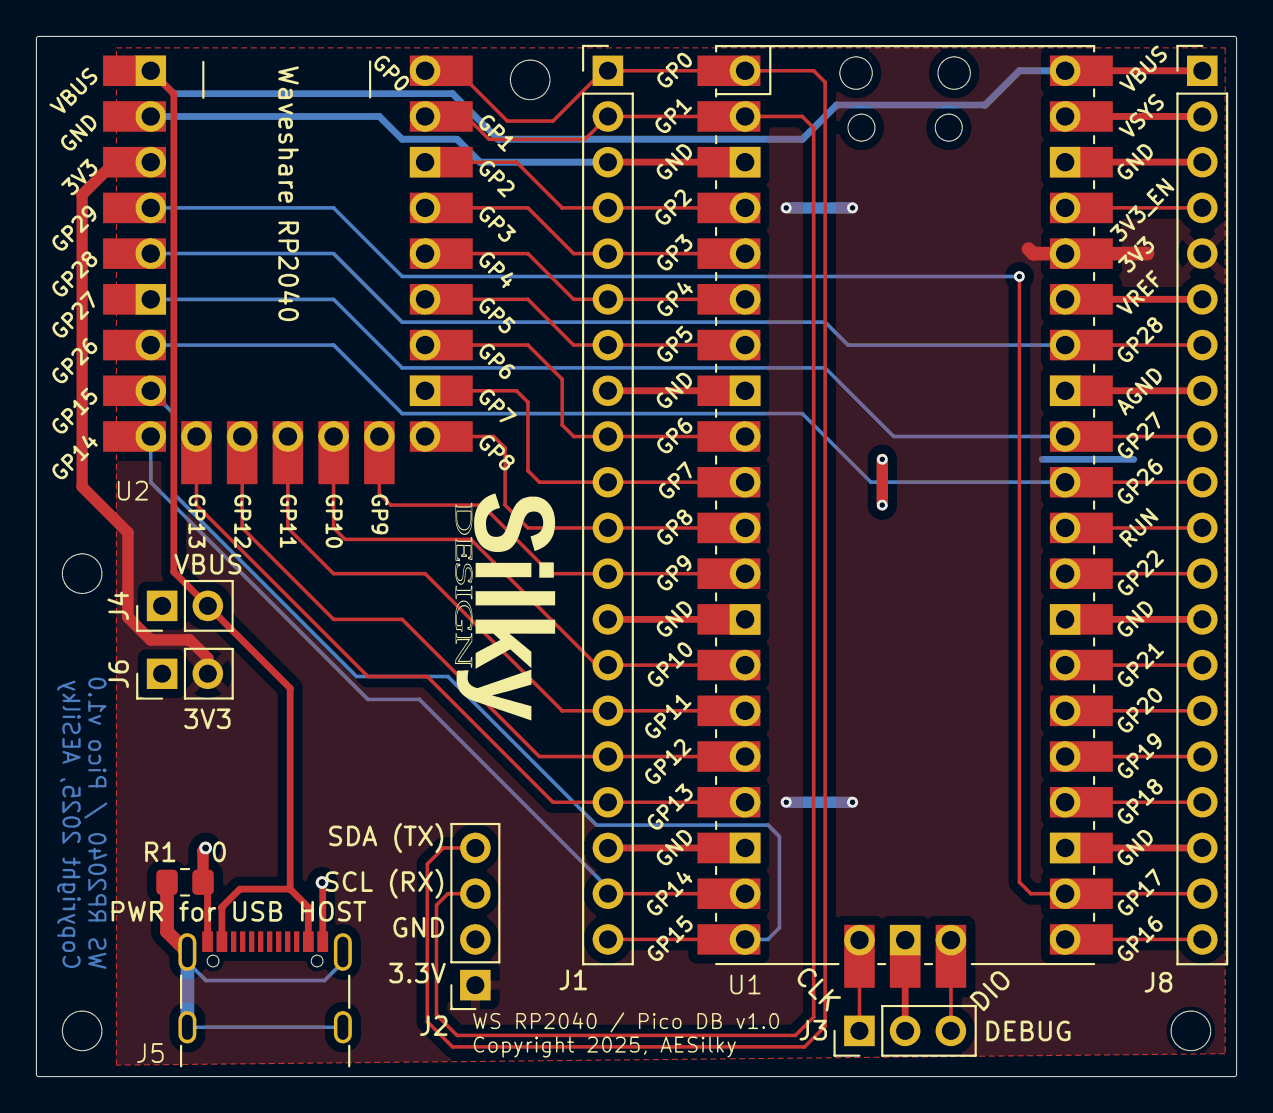
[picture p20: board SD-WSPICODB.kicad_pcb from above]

Board: 2 copper layers, 66.7 x 57.8 mm, 14 parts (0 on the bottom side), 37 nets.

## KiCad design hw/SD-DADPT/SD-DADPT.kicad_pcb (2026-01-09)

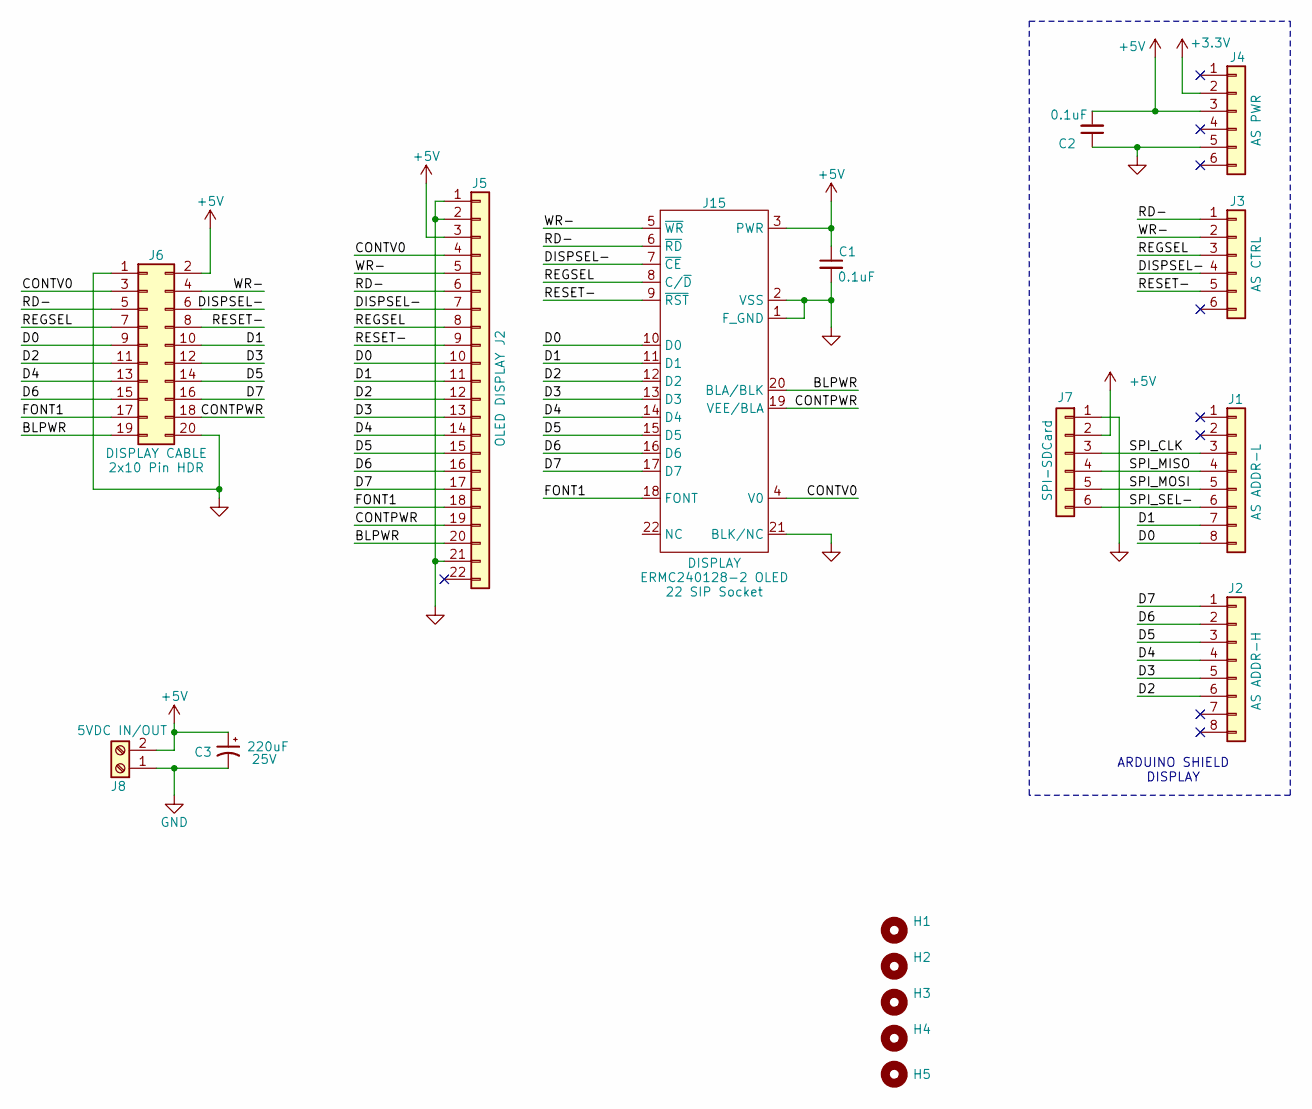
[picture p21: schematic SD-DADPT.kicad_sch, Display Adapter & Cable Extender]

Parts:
C1, C2: 0.1uF; C_0603_1608Metric_Pad1.08x0.95mm_HandSolder
C3: 220uF; CP_Radial_D6.3mm_P2.50mm; Voltage 25V
H1, H2, H3, H4, H5: MountingHole; MountingHole_3.2mm_M3
J1, J2: CONN 1x8 Socket; PinSocket_1x08_P2.54mm_Vertical
J3, J4: CONN 1x6 Socket; PinSocket_1x06_P2.54mm_Vertical
J5: CONN 1x22 SOCKET; PinSocket_1x22_P2.54mm_Vertical
J6: HDR 2x10 Pin; PinHeader_2x10_P2.54mm_Vertical; PartOpt1 2x10 Pin HDR
J7: CONN 1x6 HDR; PinHeader_1x06_P2.54mm_Vertical
J8: Screw_Terminal_01x02; AES-TermBlock-2POS-5mm-Horz
J15: DISPLAY; OLED-Disp-Socket-P2-8BitPI-AES; PartOpt1 22 SIP Socket

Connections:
+3.3V: J4.2
+5V: C1.1, C2.2, C3.1, J4.3, J5.3, J6.2, J7.2, J8.2, J15.3 (PWR)
/BLPWR: J5.20, J6.19, J15.20 (BLA/BLK)
/CONTPWR: J5.19, J6.18, J15.19 (VEE/BLA)
/CONTV0: J5.4, J6.3, J15.4 (V0)
/D0: J1.8, J5.10, J6.9, J15.10 (D0)
/D1: J1.7, J5.11, J6.10, J15.11 (D1)
/D2: J2.6, J5.12, J6.11, J15.12 (D2)
/D3: J2.5, J5.13, J6.12, J15.13 (D3)
/D4: J2.4, J5.14, J6.13, J15.14 (D4)
/D5: J2.3, J5.15, J6.14, J15.15 (D5)
/D6: J2.2, J5.16, J6.15, J15.16 (D6)
/D7: J2.1, J5.17, J6.16, J15.17 (D7)
/DISPSEL-: J3.4, J5.7, J6.6, J15.7 (~CE)
/FONT1: J5.18, J6.17, J15.18 (FONT)
/RD-: J3.1, J5.6, J6.5, J15.6 (~RD)
/REGSEL: J3.3, J5.8, J6.7, J15.8 (C/~D)
/RESET-: J3.5, J5.9, J6.8, J15.9 (~RST)
/SPI_CLK: J1.3, J7.3
/SPI_MISO: J1.4, J7.4
/SPI_MOSI: J1.5, J7.5
/SPI_SEL-: J1.6, J7.6
/WR-: J3.2, J5.5, J6.4, J15.5 (~WR)
GND: C1.2, C2.1, C3.2, J4.5, J5.1, J5.2, J5.21, J6.1, J6.20, J7.1, J8.1, J15.1 (F_GND), J15.2 (VSS), J15.21 (BLK/NC)

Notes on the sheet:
ARDUINO SHIELD DISPLAY

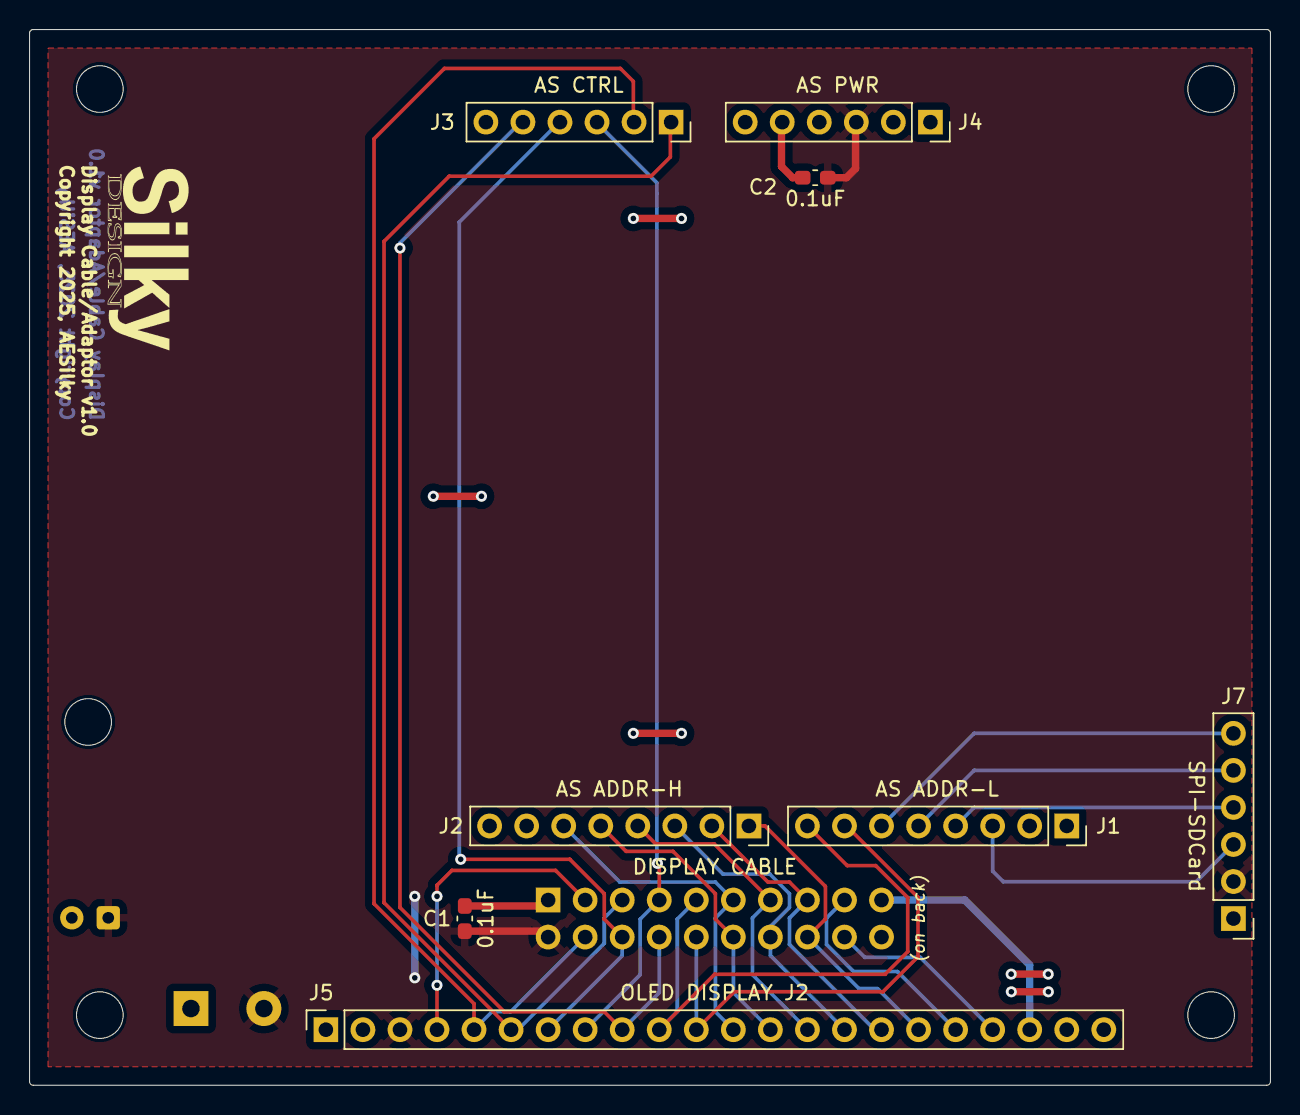
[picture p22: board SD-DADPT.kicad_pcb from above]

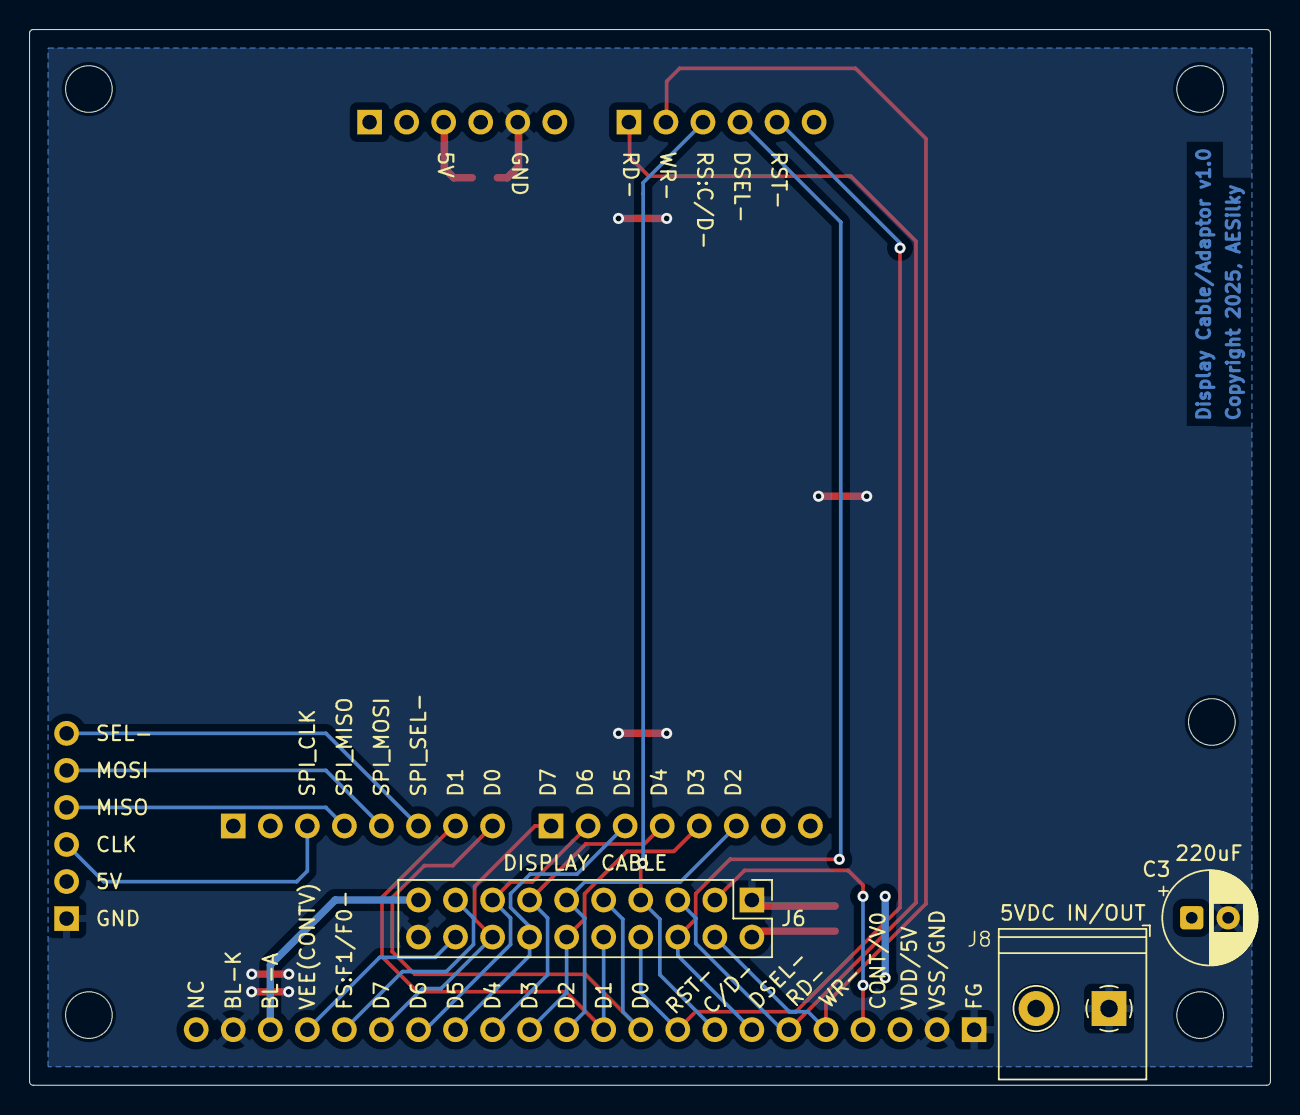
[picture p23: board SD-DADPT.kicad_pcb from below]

Board: 2 copper layers, 85.1 x 72.4 mm, 16 parts (3 on the bottom side), 23 nets.

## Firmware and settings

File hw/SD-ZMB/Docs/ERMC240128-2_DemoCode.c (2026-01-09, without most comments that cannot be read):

//----------------------------------------------------------------------
/*EASTRISING TECHNOLOGY CO,.LTD.*/
// Module    : ERMC240128-2 Series
// Lanuage   : C51 Code
// Create    : JAVEN
// Date      : Dec-12-2020
// Drive IC  : T6963
// INTERFACE : 8080_8bit
// MCU 		 : AT89C52
// VDD		 : 5V
//***************************************************************************


#include <INTRINS.H>
#include <STDIO.H>
#include <MATH.H>
#include <ABSACC.H>
#include <REG52.H>

/********************DEFINE IO********************/

sbit CD =P3^0;    	// 	COMMAND/DATA
sbit RESET =P3^1; 	//	RESET
sbit FS =P3^3;
sbit _WR =P3^6; 	//	WRITE
sbit _RD =P3^7;		//	READ
sbit	int0=P3^2;
//TP CHIP IO
sbit	DCLK   = P2^0;
sbit	TP_CS  = P2^1;
sbit	DIN    = P2^2;
sbit	BUSY   = P2^3;
sbit	DOUT   = P2^4;
sbit IRQ = P2^5;

bit log=0;
#define uchar  unsigned char
#define uint  unsigned int
#define DataBus		P1
#define Graphic		1
#define	Character 	0

uint TP_X=0;uint TP_Y=0;	   //LOCATE X AND Y OF TP

unsigned char code BMP0[];
unsigned char code BMP1[];
unsigned char code BMP2[];
unsigned char code Chinese_character[];


void Locatexy(uchar xa,uchar ya,uchar mode);
void CheckBusy_S0S1();
void CheckBusy_S2();
void CheckBusy_S3();
void WriteCommand( uchar dat1,uchar dat2,uchar command,uchar parameters_num );
void WriteData( uchar DataByte );
void LcmClear( void );
void Display_Str(uchar x,uchar y,uchar *ascll);
void Display_16_16(uchar x,uchar y,uchar  code *Chinese_character,uchar character_code);
void DisplayDots( uchar DotByte,uchar DotByte1 );
void LcmInit( void );
void DisplayBMP(uchar x,uchar y,uchar W,uchar H,  uchar  code *puts );
void ReverseDisplayBMP(uchar x,uchar y,uchar W,uchar H,  uchar  code *puts );
void Delay(uint MS);
void TestAscll(void);

void spistar();
void AD7843(void);
void inttostr(int dd,unsigned char *str);
unsigned int ReadFromCharFrom7843();
void WriteCharTo7843(unsigned char num);

/************************TP*************************/
//**********************************************************
void spistar()                                     //SPI START
{
TP_CS=1;
DCLK=1;
DIN=1;
DCLK=1;
}
//**********************************************************

void WriteCharTo7843(unsigned char num)          //SPI WRITE BYTE
{
unsigned char count=0;
DCLK=0;
for(count=0;count<8;count++)
{
num<<=1;
DIN=CY;
DCLK=0; _nop_();_nop_();_nop_();
DCLK=1; _nop_();_nop_();_nop_();
}
}
//**********************************************************

unsigned int ReadFromCharFrom7843()             //SPI READ BYTE
{
unsigned char count=0;
unsigned int Num=0;
for(count=0;count<12;count++)
{
Num<<=1;
DCLK=1; _nop_();_nop_();_nop_();
DCLK=0; _nop_();_nop_();_nop_();
if(DOUT) Num++;
}
return(Num);
}

void inttostr(int dd,unsigned char *str)
{
    str[0]=dd/10000+48;
    str[1]=(dd/1000)-((dd/10000)*10)+48;
    str[2]=(dd/100)-((dd/1000)*10)+48;
    str[3]=(dd/10)-((dd/100)*10)+48;
    str[4]=dd-((dd/10)*10)+48;
    str[5]=0;
}
void AD7843(void)
{
 TP_CS=0;
Delay(1);
//while(BUSY);
Delay(1);
WriteCharTo7843(0x90);
//while(BUSY);
Delay(1);
DCLK=1; _nop_();_nop_();_nop_();_nop_();
DCLK=0; _nop_();_nop_();_nop_();_nop_();
TP_Y=ReadFromCharFrom7843();
WriteCharTo7843(0xD0);
DCLK=1; _nop_();_nop_();_nop_();_nop_();
DCLK=0; _nop_();_nop_();_nop_();_nop_();
TP_X=ReadFromCharFrom7843();
TP_CS=1;
}



/************************LCM*************************/
/********************************************************/
  // LOCATE X AND Y OF LCM
/********************************************************/
void Locatexy(uchar xa,uchar ya,uchar mode)
{  uint a=0;
    if(mode)
        {
            a=ya*30+xa;
            WriteCommand((uchar)a,(uchar)(a>>8)+0x08,0x24,2);
        }

    else
        {
            a=ya*30+xa;
            WriteCommand((uchar)(a),(uchar)(a>>8),0x24,2);
        }

}

/***************************/
/*LCM READ AND WRITE BUSY CHECK
/***************************/

void CheckBusy_S0S1()
{uchar b;
     do
    {DataBus=0xff;
     CD=1;
     _RD=0;
     b=DataBus;
      _RD=1;
     }
     while(b&0x03!=0x03);

 }

/***************************/
/*DATA AUTO READ BUSY CHECK
/***************************/

void CheckBusy_S2()
{uchar b;
     do
    {DataBus=0xff;
     CD=1;
     _RD=0;
     b=DataBus;
     _RD=1;
     }
     while(b&0x03==0);

}


/***************************/
/*DATA AUTO WRITE BUSY CHECK
/***************************/

void CheckBusy_S3()
{uchar b;
     do
    {DataBus=0xff;
     CD=1;
     _RD=0;
     b=DataBus;
     _RD=1;
     }
     while(b&0x08!=0x08);
}



/***************************/
/*WRITE COMMAND             */
/***************************/
void WriteCommand( uchar dat1,uchar dat2,uchar command,uchar parameters_num )
{
  if((parameters_num==1)|(parameters_num==2))
      {CheckBusy_S0S1();
      WriteData(dat1);
    }
  if(parameters_num==2)
      {CheckBusy_S0S1();
      WriteData(dat2);
    }

    CheckBusy_S3();
     CD = 1;
     DataBus = command;
     _WR = 0;
    _nop_();
     _WR  = 1;

}


/***************************/
/*WRITE DATA                 */
/***************************/
void WriteData( uchar DataByte )
{
     CD = 0;
     DataBus = DataByte;
     _WR = 0;
    _nop_();
     _WR  = 1;
}

void LcmClear( void )
{   uint a;
    Locatexy(0,0,Character);
    WriteCommand(0,0,0xb0,0 );
    for(a=0;a<8192;a++)
    {
        WriteData( 0 );
    }
    WriteCommand(0,0,0xb2,0 );
}

void Display_Str(uchar x,uchar y,uchar *ascll)
{
    Locatexy(x,y,Character);
    while(*ascll>0)
    {
        WriteCommand(*ascll-0x20,0,0xc0,1 );
        ascll++;
    }
}


void Display_16_16(uchar x,uchar y,uchar  code *Chinese_character,uchar character_code)
{	uchar k,j;    uint	num=0;
     num=character_code*0x20;
    Locatexy(x,y,Graphic);
    for(j=0;j<16;j++)
        { for(k=0;k<2;k++)
            {
                WriteCommand(*(Chinese_character+num),0,0xc0,1 );
                num++;
            }
            y+=1;
            Locatexy(x,y,Graphic);
        }

}

void DisplayDots( uchar DotByte,uchar DotByte1 )
{ 	uchar k,j;
    Locatexy(0,0,Graphic);
     WriteCommand(0,0,0xb0,0 );
     for(j=0;j<64;j++)
     {
      for(k=0;k<30;k++)
        {
            WriteData(DotByte);

        }
      for(k=0;k<30;k++)
        {
            WriteData(DotByte1);

        }
      }
      WriteCommand(0,0,0xb2,0 );
}


void DisplayBMP(uchar x,uchar y,uchar W,uchar H,  uchar code *puts )
{  	uchar k,j;
    Locatexy(x,y,Graphic);

    for(j=0;j<H;j++)
        {	WriteCommand(0,0,0xb0,0 );
             for(k=0;k<W/8;k++)
            {
                WriteData(*puts++);

            }
        WriteCommand(0,0,0xb2,0 );
            y+=1;
            Locatexy(x,y,Graphic);
        }
}
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

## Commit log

2025-09-23 Update gitignore to skip KiCad lock and backup files.
    [SD-FPRC.kicad_pcb, SD-FPRC.kicad_sch, SD-MSZ.kicad_sch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]
2025-10-09 HW: PR4 CPU, Memory, page cleaner.
    [SD-FPRC.kicad_pcb, SD-FPRC.kicad_sch, SD-ZMB.kicad_pcb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]
2025-10-09 History: Add PR4
    [SD-ZMB.kicad_pcb, SD-ZMB.kicad_sch, exp-ifc.kicad_sch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]
2025-10-10 PR: PR6, 2 addr busses, exp buffered.
    [SD-ZMB.kicad_pcb, SD-ZMB.kicad_sch, exp-ifc.kicad_sch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]
2025-10-11 PR7: Review
    [SD-ZMB.kicad_sch, exp-ifc.kicad_sch, logic_pwr_spr.kicad_sch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]
2025-10-13 PR7.4: checkpoint only
    [SD-DBG.kicad_pcb, SD-DBG.kicad_sch, SD-ZMB.kicad_sch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]
2025-10-13 DBG: PR1.0, ZMB PR7.5, Timing diagrams
    [SD-DBG.kicad_sch, SD-ZMB.kicad_pcb, SD-ZMB.kicad_sch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]
2025-11-05 ZMB: Diagrams and start of PCB. DBG: Updated WAIT. DADPT: Display/Cable PCB ordered.
    [SD-DADPT-B_Cu.gbr, SD-DADPT-B_Mask.gbr, SD-DADPT-B_Silkscreen.gbr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]
2025-11-24 ZMB: v1.0 Board RFP
    [SD-DADPT-B_Cu.gbr, SD-DADPT-B_Mask.gbr, SD-DADPT-B_Silkscreen.gbr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]
2025-11-24 ZMB: v1.0 w/Spares added. RFP
    [SD-DBG.kicad_sch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]
2025-11-25 ZMB gerbers created. OLED display portion updates.
    [SD-DADPT-B_Cu.gbr, SD-DADPT-B_Mask.gbr, SD-DADPT-B_Silkscreen.gbr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]
2026-01-08 PCB received
    [SD-DBG.kicad_sch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]
2026-02-07 Prep for ECO-A
    [SD-ZMB.kicad_sch, ZMB_bom-trbl.csv, ZMB_bom-trbl.xlsx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]
2026-02-12 ECO.A: PG Reg A3 incorrect. Change U17B AND to SPR.1A OR
    [SD-ZMB.kicad_sch, exp-ifc.kicad_sch, logic_pwr_spr.kicad_sch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]
2026-03-03 ECO.A: MMU PageReg PRA3 s/b 74AHCT32
    [logic_pwr_spr.kicad_sch]
2026-03-07 ECO-A: Updated schematic plots
2026-03-08 excel recovery file update
    [ZMB_bom-trbl.xlsx]

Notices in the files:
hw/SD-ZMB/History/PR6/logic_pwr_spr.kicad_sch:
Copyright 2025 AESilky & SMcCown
